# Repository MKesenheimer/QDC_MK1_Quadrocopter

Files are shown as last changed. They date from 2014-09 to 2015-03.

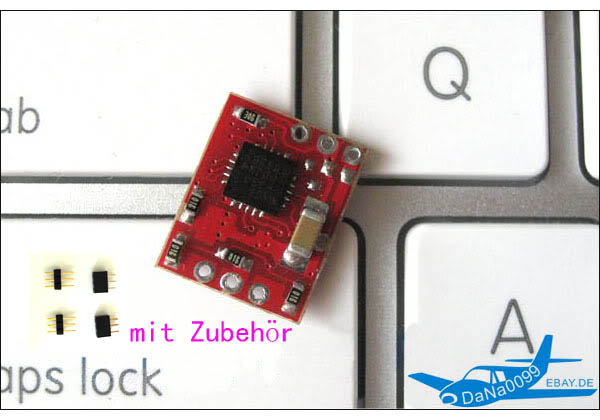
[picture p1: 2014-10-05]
hardware/Motoren + Sonstiges/yu3A.jpg

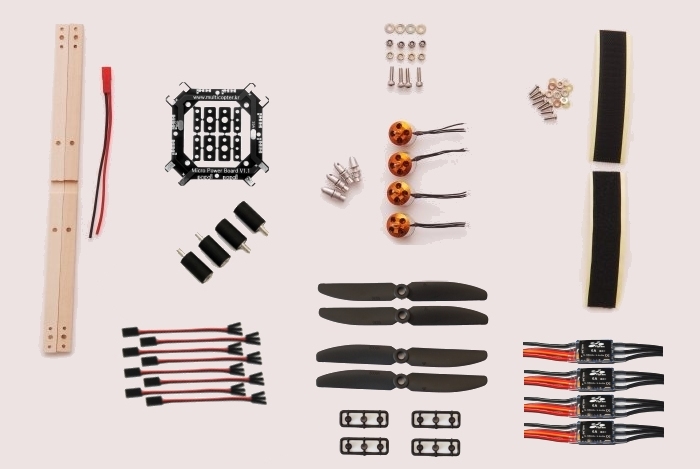
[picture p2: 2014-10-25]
hardware/Ideen/Microcopter.kr/microfullset_1.jpg

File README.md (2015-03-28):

QDC MK1 Quadrocopter
====================

Software für einen Miniatur Quadrocopter (Nanocopter) auf Grundlage der MultiWii-Software. Es wird kein Arduino, sondern ein eigenständiger Flightcontroller (AtXmega32A4) verwendet. Die Software, mit der der Quadrocopter kalibriert werden kann, läuft momentan nur unter Mac OS X.

Um die Software zu kompilieren, müssen die Mac OSX Entwicklertools (XCode) oder GNU g++ installiert sein. Außerdem wird avr-gcc und ein Hardware Programmer (z.B. JTAGICE 3) benötigt.

Kompilieren und Hochladen über PDI der Firmware auf den Quadrocopter:
---------------------------------------------------------------------
- cd firmware
- ./make_Wall oder ./make
- make flash

Erzeugen der GUI QuadroCalibration:
-----------------------------------
- QuadroCalibration.xcodeproj mit XCode öffnen
- kompilieren

Sonstiges:
----------
- der Quadrocopter muss über die serielle Schnittstelle USARTD1 mit dem Computer verbunden werden. Dazu bietet sich ein Arduino an, der standardmäßig ein USB-zu-Seriell-Konverter besitzt. Wichtig: Pegel von 3.3V nicht überschreiten!
- an der seriellen Schnittstelle USARTD0 muss der RC-Empfänger angeschlossen werden (nicht im Schaltplan verzeichnet). In dieser Software Version wird ein DSM2 fähiger Deltang rx31b-K1 verwendet.

Der Quadrocopter lässt sich über eine bestimmte Hebelstellung der Fernsteuerung scharfstellen (Motoren an/aus) und neu initialisieren (Selbstkalibrierung von GYRO und ACCELEROMETER). Siehe dazu main.c 

Bekannte Fehler
---------------
- kein Failsafe implementiert
- keine Spannungsüberwachung
- PID-Werte noch nicht optimal

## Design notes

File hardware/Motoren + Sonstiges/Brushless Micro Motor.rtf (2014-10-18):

Brushless Micro Motor:

http://www.hobbyking.com/hobbyking/store/__9666__hobbyking_ap_02_7000kv_brushless_micro_motor_2_3g_.html

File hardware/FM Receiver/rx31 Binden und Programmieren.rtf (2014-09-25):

Binden und Programmieren von rx31 (RX, Receiver) und DX6i (TX, Transmitter)

Binden
Um RX und TX zu Binden, muss die LED vom RX schnell blinken. Dazu schält man den RX ein und wartet mehrere Minuten. Das anfängliche langsame Blinken der LED geht nun in ein schnelles Blinken über und der RX ist bereit mit einem TX verbunden zu werden. Jetzt kann der TX mit gedrückter Trainer-Taste eingeschaltet werden, was das Binden von RX und TX einleitet.

Programmieren
Es gibt für den Receiver rx31 mehrere Möglichkeiten die empfangenen Rc-Werte auszugeben. Um zwischen den Modi zu wechseln, muss der RX umprogrammiert werden. Das Programmieren kann nach dem Binden von RX und TX wie folgt eingeleitet werden:
- RX ausschalten (von Spannungsquelle trennen)
- TX einschalten
- rechten und linken Steuerknüppel in die Mitte drücken (d.h. YAW nach rechts und ROLL nach links)
- RX einschalten, während die Steuerknüppel in die Mitte gedrückt werden, blinkt die LED des RX sehr schnell, das Programmieren ist bereit.

Es gibt zwei Programm Level
Level 1: Low Voltage Cutoff (brushed ESC only)
1x pro Sekunde Blinken: Disabled
2x pro Sekunde Blinken: Enabled (Default)

Level 2: Servo/Sum-PPM outputs
1x pro Sekunde Blinken: Sum-PPM on Pin3
2x pro Sekunde Blinken: Serial Data on Pin3
3x pro Sekunde Blinken: Servo outputs on all pads (Default)

Der RX zeigt nun seine derzeitige Konfiguration des ersten Programm Levels an. Blinkt er nach dem Einleiten der Programmieren ein mal pro Sekunde, heißt das, dass die Option Low Voltage Cutoff ausgeschaltet ist. Blinkt er zwei mal pro Sekunde ist die Option Low Voltage Cutoff eingeschaltet. Die derzeitige Option kann entweder mit dem rechten Steuerknüppel nach oben (NICK nach oben) akzeptiert oder mit dem rechten Steuerknüppel nach unten (NICK nach unten) verweigert werden. Wird die Option akzeptiert, geht der RX zum zweiten Level über und zeigt dort seine Konfiguration mit der entsprechenden Anzahl von Blinken pro Sekunde an. Wird die derzeitige Option allerdings verweigert, wechselt der RX zur nächsten Option, die entweder akzeptiert (weiter zum nächsten Level) oder verweigert werden kann (weiter zur nächsten Option des derzeitigen Levels).

Beispiel:
Der RX befindet sich im Werkszustand, d.h. er blinkt im ersten Level zwei mal pro Sekunde und im zweiten Level drei mal pro Sekunde.
Nun soll die folgende Konfiguration eingestellt werden:
- Low Voltage Cutoff disabled
- Serial on Pin3
Nach dem Starten des Programmiervorgangs blinkt der RX zwei mal pro Sekunden (Low Voltage Cutoff enabled). Diese Option verweigert man mit dem rechten Knüppel nach unten, weshalb der RX nun zur nächsten Option wechselt, was daran zu erkennen ist, dass der RX nur noch ein mal pro Sekunde blinkt (Low Voltage Cutoff disabled). Akzeptiert man mit dem rechten Steuerknüppel nach oben, wechselt der RX zum zweiten Programm Level und blinkt drei mal pro Sekunde. Nachdem der rechte Steuerknüppel zwei mal nach unten gedrückt wurde, ist die Option 2 ausgewählt (Serial on Pin3) und der RX blinkt zwei mal pro Sekunde. Akzeptiert man mit dem Steuerknüppel nach oben, wird die LED statisch und das Programmieren ist beendet.

Kurzversion Serial on Pin3:
(rechter Steuerknüppel nach oben H, rechter Steuerknüppel nach unten L)
Level 1:
2x Blinken: L
1x Blinken: H (Low Voltage Cutoff disabled)
-> Level 2:
3x Blinken: L
1x Blinken: L
2x Blinken: H (Serial on Pin3)
-> LED statisch

Kurzversion SUM-PPM on Pin3:
Level 1:
2x Blinken: L
1x Blinken: H (Low Voltage Cutoff disabled)
-> Level 2:
3x Blinken: L
1x Blinken: H (SUM-PPM on Pin3)
-> LED statisch

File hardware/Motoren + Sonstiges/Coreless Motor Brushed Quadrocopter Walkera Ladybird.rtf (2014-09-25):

Coreless Brushed Motor

3.7V Operating Voltage
7mm chasis Diameter
<20mm chasis length
1mm shaft diameter
0.5mNm Torque

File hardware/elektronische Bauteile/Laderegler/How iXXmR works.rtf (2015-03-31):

The way it works is when the USB power (or adapter) is not present, the VUSB_IN line gets pulled to 0V by R4. This brings the gate of the PMOS (G on the symbol) to ground and turns it on (i.e. opens the Source-Drain, marked S and D) allowing the battery to power the circuit. The Schottky (marked A and K) stops the battery raising the VUSB_IN line and turning the PMOS off again.
when the adapter is plugged in, the gate is pulled to +5V and the PMOS turns off, leaving only the adapter voltage powering the circuit and letting the battery charge.

More Current:
IRF7321D2

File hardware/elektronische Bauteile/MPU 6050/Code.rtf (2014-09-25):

Example Code

https://github.com/jrowberg/i2cdevlib

https://github.com/big5824/Quadrocopter
http://www.botched.co.uk/page/2/

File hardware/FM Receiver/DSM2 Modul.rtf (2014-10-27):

DSM2 Modul direkt auf Platine

deltang Dx31c
cyrf69103
http://deltang.co.uk/rx31b.htm

Forum Eintrag:
http://fpv-community.de/showthread.php?21520-DSM2-Nano-Empf%E4nger-auf-Nano-BL-Copter

Cyrf6936 Modul und Erklärung
https://sites.google.com/site/mrdunk/interfacing-cypress-cyrf6936-to-avr-microcontrollers

Software:
https://bitbucket.org/MatCat/letsfpv-deviation
https://bitbucket.org/MatCat/letsfpv-deviation/src

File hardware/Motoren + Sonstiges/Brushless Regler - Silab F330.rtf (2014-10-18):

Brushless Regler - eigene Platine

Als Regler habe ich eigentlich auch die kleinen 3A Regler vom Chinesen, aber eben auf meiner eigenen Platine. Das ist nichts weiter als ein Silab F330 Prozessor, ein paar wenige Widerstände und Kondensatoren und die 6 Mosfets. Als Software kann man dann die Blheli Software flashen, die kennst Du vielleicht.
Das ist der kleinste Brushlessregler den ich finden konnte, den Schaltplan gibt es glaube ich im Netz (sonst kann ich ihn dir aber auch schicken). Habe mal noch einen winzigen Chip für Laptoplüfter getestet, der war gerade mal 3x3mm groß, aber leider kam er mit den üblichen Brushlessmotoren nicht klar.

Siehe auch
http://plischka.at/Regler.html

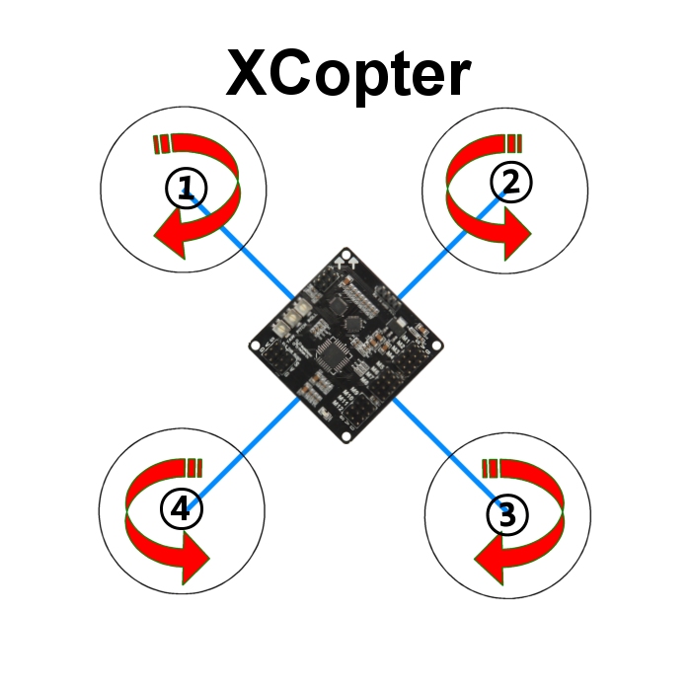
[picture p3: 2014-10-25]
hardware/Ideen/Microcopter.kr/black_x.jpg

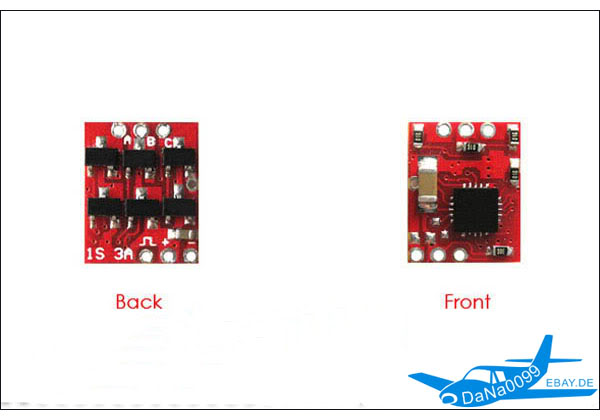
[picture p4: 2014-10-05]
hardware/Motoren + Sonstiges/ezbl-3a-1.jpg

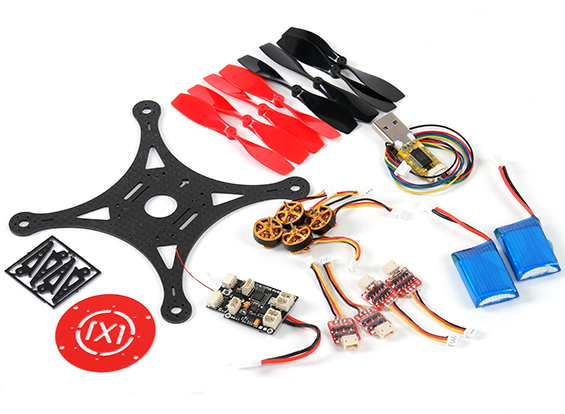
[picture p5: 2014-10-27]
hardware/Ideen/Super X.jpg

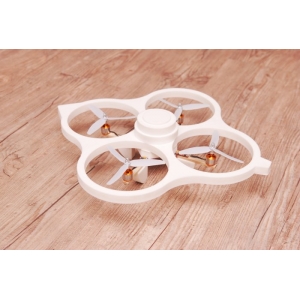
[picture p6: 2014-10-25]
hardware/Ideen/Microcopter.kr/g201207311445_152_detail.jpg

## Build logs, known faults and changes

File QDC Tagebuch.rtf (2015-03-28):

Arbeit am Quadrocopter
Oder falls das zu blöd wird: https://www.kickstarter.com/projects/1387330585/hex-a-copter-that-anyone-can-fly

15. - 16. Februar 2013:
Arbeit an xNQ_QDC_gemeinsam: Ich arbeitete weiterhin am Problem, dass die Kommunikation nicht zustande kam, wenn die UARTD0-GUI und die UARTD1-RECEIVER Schnittstelle eine zu hohe Priorität hatten. Das Problem wurde letztendlich dadurch gelöst, dass die BAUDRATE zur GUI Kommunikation mit 115200 zu groß war. Ein Reduzieren auf 19200 löste das Problem. Dadurch musste aber die MultiWii-GUI neu kompiliert werden (mit dem Programm „Processing“), da man in der GUI blöderweise die BAUDRATEs nicht ändern konnte. Außerdem musste in die Main wieder die 20ms-Abfrage eingebaut werden, damit der Mikrokontroller nicht mit der Aufgabe die RC-Daten einzulesen überlastet wurde. Die Konfiguration der seriellen Schnittstellen sieht nun so aus:

USARTD0-GUI:
- BAUD 19200
- Priorität niedrig

USARTD1-RECEIVER:
- BAUD 38400
- Priorität niedrig

Der Timer E0, der einen 10ms Interrupt aufruft, hat eine mittlere Priorität.
Da zuerst überhaupt keine RC-Daten vom RECEIVER empfangen werden konnten (mit QDC_Main_Tests_DSL getestet), musste die Initialisierung des UARTs geändert werden.
Die Variable ms10 war ursprünglich eine uint16_t Variable, was allerdings zu Problemen führte, weil sie überlief. Sie wurde auf uint32_t geändert.

noch Problem: Die RC-Daten werden nicht korrekt empfangen. Wird der Sender angeschaltet, verändern sich zwar kurz die Werte in der MultiWii-GUI, aber sie lassen sich nicht mit den Steuerknüppeln ändern. Ich vermute, dass noch irgendetwas mit den Interrupts nicht stimmt oder dass in receive.c noch ein Fehler ist.
Dazu hab ich mir meine alten Codes (z.B. BIG5824) angeschaut, wo die RC-Daten korrekt übertragen werden.

Arbeit an QDC_Main_Project_BIG5824: Alle _delay_ms() wurden durch _delay_loop_2() ausgetauscht. Ich vermutete, dass die alten Warteschleifen Probleme bereiteten. Dem war aber nicht so. Der Timer-Aufruf von E0 wurde so geändert, dass er nur noch alle 10ms einen Interrupt auslöst. Damit verhindere ich hohe Interruptauslastung.

Arbeit an QuadroCalibration: Aufgrund der Hardwareänderung, dass die Kommunikation jetzt nicht mehr über den Arduino, sondern direkt über die serielle Schnittstelle läuft, wurde der Default-Wert beim PopUp der BAUDRATEs auf 19200 geändert.

23. Februar
Arbeit an xNQ_QDC_gemeinsam: Das Empfangen der RcDaten funktioniert einigermaßen. Ich bin mir noch nicht sicher, ob die Kanalzuordnung stimmt. Zuerst änderten sich die Werte in der GUI nicht (Fehler der vergangenen Woche), weil das Intervall der rcData[] Werte nicht passte und ein Constrain() sie auf 100 einschränkte. Außerdem kalibriert sich das ACC manchmal wieder neu, danach hatte ACC_Z einen zu niedrigen Wert. Letzteres wurde dadurch korrigiert, dass das Vorzeichen beim Lesen der ACC_Z Werte aus dem ADC geändert wurde. Nun können die ACC_Z Werte allerdings nach einem Kalibrationsvorgang sehr groß sein, was allerdings egal ist, denn sie werden jetzt wieder richtig korrigiert. Das zufällige Einsetzen der Kalibration bleibt allerdings weiterhin ungeklärt. Vielleicht hat es tatsächlich mit Störungen des RC_Empfängers zu tun oder die Kalibrationsvorgänge werden durch die GUI getriggert. Diese Idee ist vielleicht gar nicht so abwegig, denn der QDC kalibriert sich nicht neu, wenn er nicht an die GUI angeschlossen ist.
Bleibt also noch die Frage zu klären, warum ein Kalibrationsvorgang ausgelöst wird, wenn rcData[ROLL] oder PITCH sehr groß ist -> sind das die f.ARMED Abfragen?

8. Juli (Updates vom 22. September)
Hinweise: Es ist jedes mal ein Problem alles zum Laufen zu bekommen, wenn man schon lange nichts mehr am Quadrocopter gearbeitet hat. Deshalb hier die Kurzzusammenfassung, was getan werden muss um den Quadrocopter mit dem Host (Computer) zu verbinden.
- Um den Quadrocopter mit dem Programm MultiWiiConf (zu finden in Firmware QDC MK I/Host Software) zu verbinden muss der Quadrocopter mit der Firmware xNQ_QDC_gemeinsam geflasht werden.
- Um den Quadrocopter mit dem Programm QuadroCalibration zu verbinden muss der Quadrocopter mit der Firmware QDC_Main_Project oder QDC_Main_Project_BIG5824 geflasht werden.
- Auf der Arduino-Seite reicht es die Datenleitungen (gelb und weiß) in die schwarze Headerleiste einzustecken. Es muss keine spezielle Software auf den Arduino installiert werden. Zur Sicherheit kann das Programm SoftwareSerial (zu finden in Firmware QDC MK I/Host Software/Arduino Programm/SoftwareSerial) geladen werden.
- Außerdem darauf achten, dass die Spannung des Arduinos auf 3.3V eingestellt ist!
- Falls die Verbindung nicht zustande kommt, den Quadrocopter neu starten oder den Akku des Quadrocopters aufladen.

Arbeit an DSM2 Übertragung: Weiterhin Problem, dass die RC-Roll-Werte nicht ankommen. Mit dem Arduino-Oszilloskop wurde allerdings gemessen, dass sich die Impulsbreite ändert, wenn der Roll-Knüppel bewegt wird. Also kann es nicht an der Fernsteuerung liegen. Liegt es am rx31 oder an der Software?

17. Juli
Arbeit an der Hardware: Endlich! Das Problem mit den Roll-Werten ist gelöst! Nachdem ich einen neuen Empfänger rx31c-K1 gekauft habe, funktioniert alles auf Anhieb. Den alten Empfänger (rx31b-F) konnte ich Umtauschen und erhielt dafür einen weiteren rx31c-K1, den ich nun in Domis Quadrocopter einbaue.
Der 35MHz Sender (Robbe Futaba FX-14) wird nun auf Ebay verkauft und dafür ein „Pommessender“ MLP4DSM oder LP5DSM von E-FLITE für Domi gekauft.

7. September
Arbeit an den TODOs: QDX_Main_Project lässt sich nun wieder kompilieren. (Klammerfehler in config.c)

19. September
Arbeit an der Hardware: Beide Quadrocopter wurden nun mit dem rx31c-K1 aufgerüstet, sodass beide Quadrocopter mit der DX6i, d.h. Spektrum-fähig sind. Hier die neue Übersicht der belegten Ports:
USARTD0: rx31c-K1 Empfänger
USARTD1: Debug-Schnittstelle zum Host
Außerdem wurde ein Splitter gebaut, der die serielle Debug-Schnittstelle von der JTAGICE3-Schnittstelle trennt. Jetzt kann gleichzeitig programmiert und auf der Debug-Schnittstelle Daten gesammelt werden, ohne dass umgesteckt werden muss!
Arbeit an QDC_Main_Project: Hier wurde mit der Umstellung des Programmcodes auf die neue Verkabelung begonnen (RC=USARTD0, DEBUG=USARTD1).
Allerdings funktioniert das Empfangen der RC-Daten noch nicht (TODO!).

22. September
Arbeit an QDC_Main_Project_BIG5824: Die Software wurde auf die Verkabelung mit dem rx31c-K1 Empfängers umgestellt. Die Warnungen wurden entfernt.
Arbeit an QDC_Main_Project: Die Software wurde auf die Verkabelung mit dem rx31c-K1 Empfängers umgestellt. Die Warnungen wurden entfernt.

23.-24. September
Arbeit an QDC_Main_Project_BIG5824:
- Blinken der LEDs wurde eingebaut
- Ausgabe auf die Motoren wurde programmiert
- Verbesserungen am PID Algorithmus
- erste Versuche den Quadrocopter mit dieser Software fliegen zu lassen -> PID muss noch besser eingestellt werden

25. September
Arbeit an QDC_Main_Project_BIG5824: Ein Kalman Filter wurde erfolgreich implementiert. Dazu war http://robottini.altervista.org/tag/complementary-filter hilfreich.
Das ganze Quadrocopter Projekt wurde ein bisschen besser strukturiert und auf Github hochgeladen. Das Projekt heißt jetzt "QDC_MK1_Quadrocopter" und ist ein Ableger von QDC_Main_Project_BIG5824.
QDC_Main_Project_BIG5824 heißt jetzt QDC_MK1_Quadrocopter.
Außerdem wurde serial.c überarbeitet. Der Code ist nun eleganter und kürzer.

26.-29. September
Arbeit an QDC_MK1_Quadrocopter: In der GUI wurde eine Debug-Option eingebaut. Jetzt können mit Check-Boxen zehn verschiedene Debug-Werte ausgewählt und geplottet werden. Das Programm kann noch mit dem Einsatz von Arrays verbessert werden.
Außerdem werden die Motorwerte und die cycle time während der Konfiguration angezeigt, was ebenfalls die Fehlersuche bzw. das Einstellen des QDC erleichtert. In pid.c wurde der Constrain der Integralwerte herabgesetzt, so reagiert der QDC schneller auf andauernde Störungen. Der LowPassFilter wurde wieder auf 42Hz geändert und der SecondOrderComplementaryFilter wird wieder benutzt, was denke ich gute Resultate erzielt.
Flugversuche sehen vielversprechend aus.

30. September
Arbeit an den PID-Werten: Beim Einstellen und Testen der PID-Werte ging ein Motor kaputt. Vier neue Motoren bei Ebay bestellt.

06. Oktober bis -
Arbeit an Schaltplan für Version 2:
Für die zweite Version des Quadrocopters sind einige Verbesserungen vorgesehen:
- prinzipiell sind für die Version 2 zwei Platinen vorgesehen. Auf der ersten befindet sich die Flugsteuerung (IMU, µC, PWM-Ausgang, Receiver-Eingang) und auf der zweiten die Motortreiber, Spannungsversorgung, Laderegler usw. Die zweite Platine dient gleichzeitig als Rahmen und Motorhalter. Beide Platinen könnten über UART miteinander verbunden werden (was allerdings einen zweiten µC auf der Motorplatine nötig macht).
- Die Platine für die Flugsteuerung soll wie die CC3D oder MultiWii mehrere Quadrocopter-Arten (Quadrocopter, ) ansteuern können.
- Brushless Motoren (z.B. HobbyKing 7000kv Brushless Micro Motor) sollen mit Onboard-Reglern (SiLab F330 und Blheli Software) nativ angesteuert werden können (keine zusätzlichen Platinen)
- Brushed Motoren sollen weiterhin unterstützt werden
- Laderegler für das Laden des LiPos über USB
- Power über USB (Programmieren, Parameter, Debug)
- Flugsteuerung auf extra Platine, die mit Schaumstoff vom Rest der Platine entkoppelt wird (bessere Störungsentkopplung)
- ggf. werden Ausleger und Motorbefestigungen geändert
- besseres Routing

TODO:
- TODOs in IMU.c
- Ausprobieren: Kalman Filter, DLPF = 12.5Hz (http://www.instructables.com/id/PCB-Quadrotor-Brushless/?ALLSTEPS, Video ganz unten)
- Platine für Version 2 vorbereiten. Der Gyro und Acc soll außerdem durch einen Kompass erweitert werden: MPU9150
- Rext gegen 120Ohm austauschen
- Für Brushless Betrieb: EAZY 3A (ESC)
- Lipo Laderegler: http://www.roboternetz.de/community/threads/61909-nanoCopter-Projekt

In ferner Zukunft TODO:
- Die serielle Kommunikation in QuadroCalibration.app ändern: Erst auf Nachfrage der GUI soll der QDC einen bestimmten Wert senden.

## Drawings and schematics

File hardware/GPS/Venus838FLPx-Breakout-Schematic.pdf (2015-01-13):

D

6 | 5 | 4 | 3 | 2 | 1

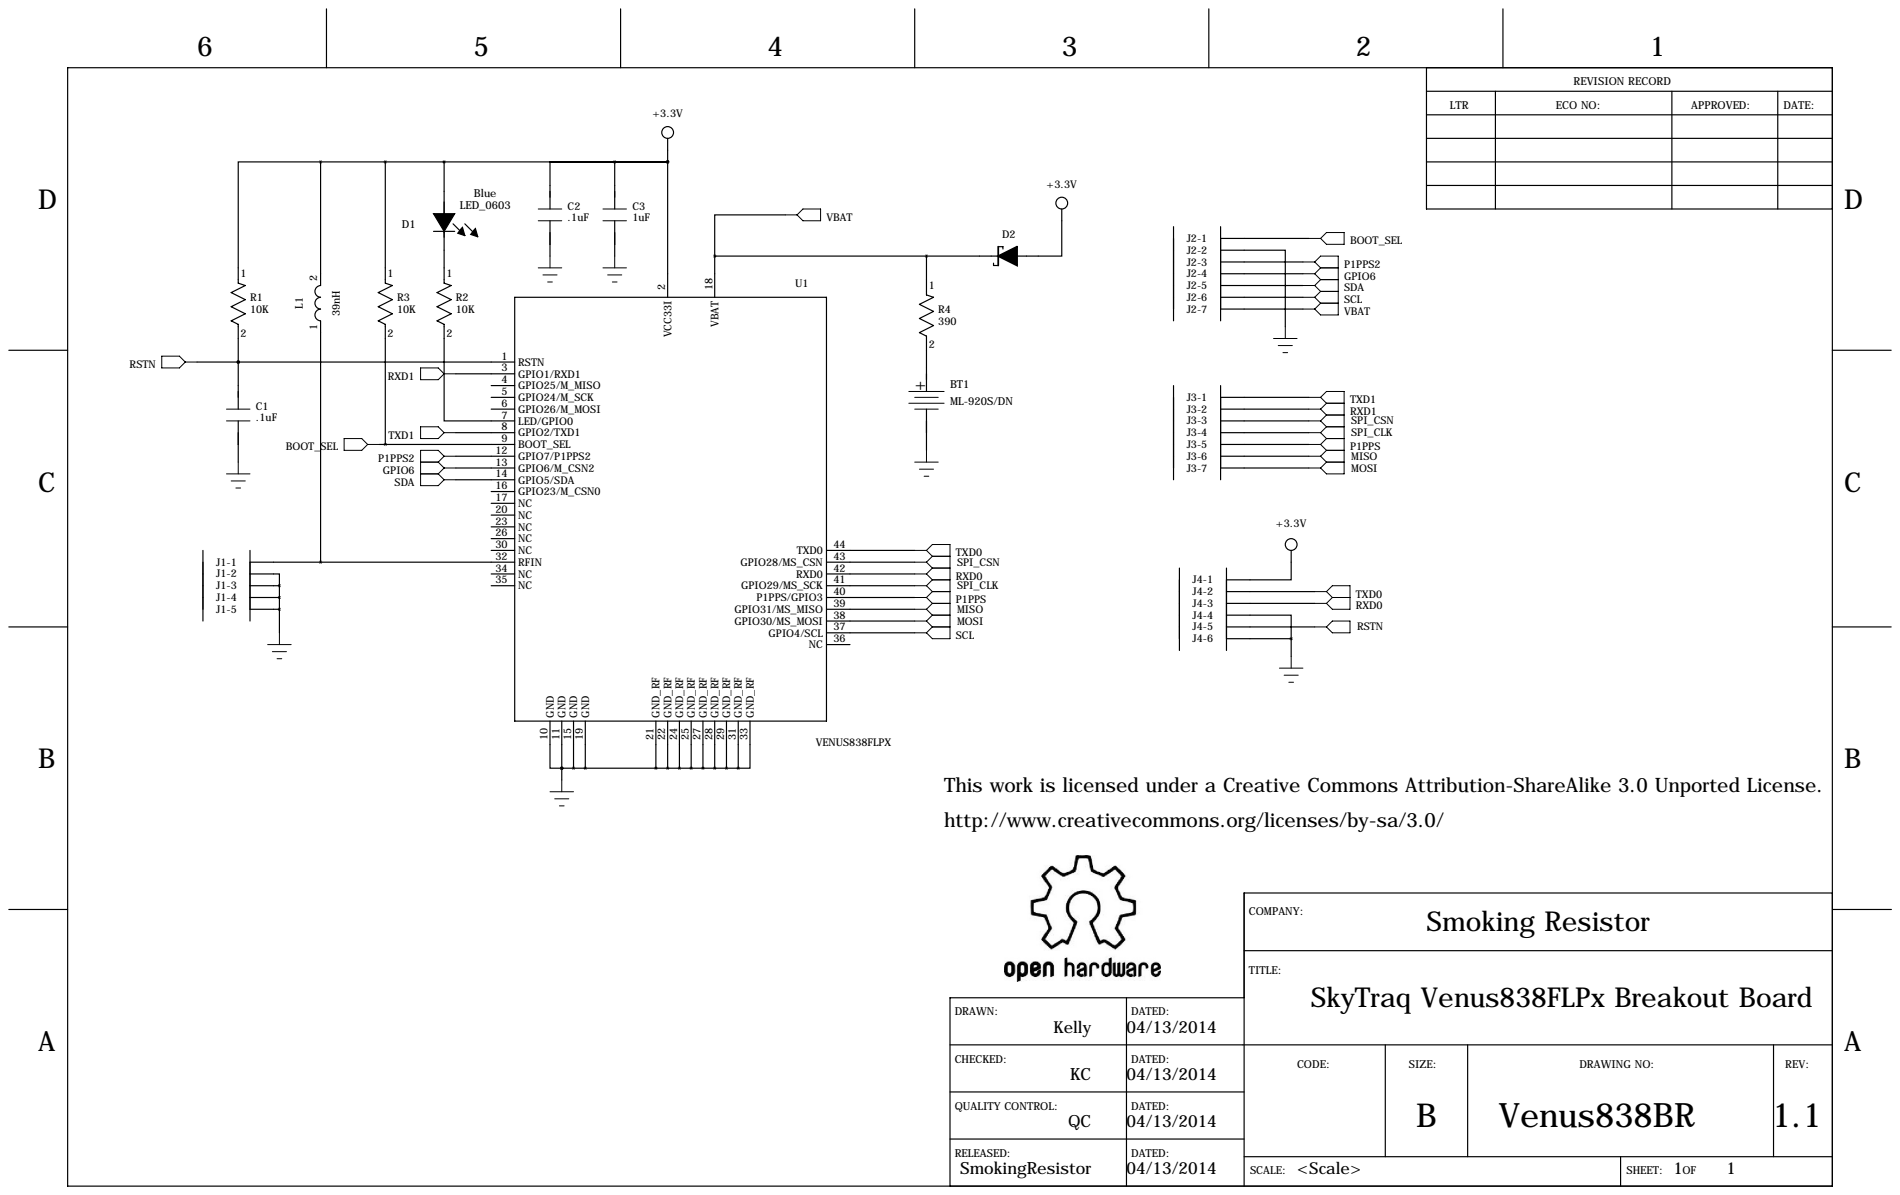
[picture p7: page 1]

+3.3V | REVISION RECORD

LTR | ECO NO: | APPROVED: | DATE:

This work is licensed under a Creative Commons Attribution-ShareAlike 3.0 Unported License.

http://www.creativecommons.org/licenses/by-sa/3.0/

DRAWN: Kelly | DATED: 04/13/2014
CHECKED: KC | DATED: 04/13/2014 | CODE: | SIZE: B | DRAWING NO: Venus838BR | REV: 1.1

QUALITY CONTROL: QC | DATED: 04/13/2014

RELEASED: SmokingResistor | DATED: 04/13/2014

<Scale> SCALE: | 1 1 SHEET: OF

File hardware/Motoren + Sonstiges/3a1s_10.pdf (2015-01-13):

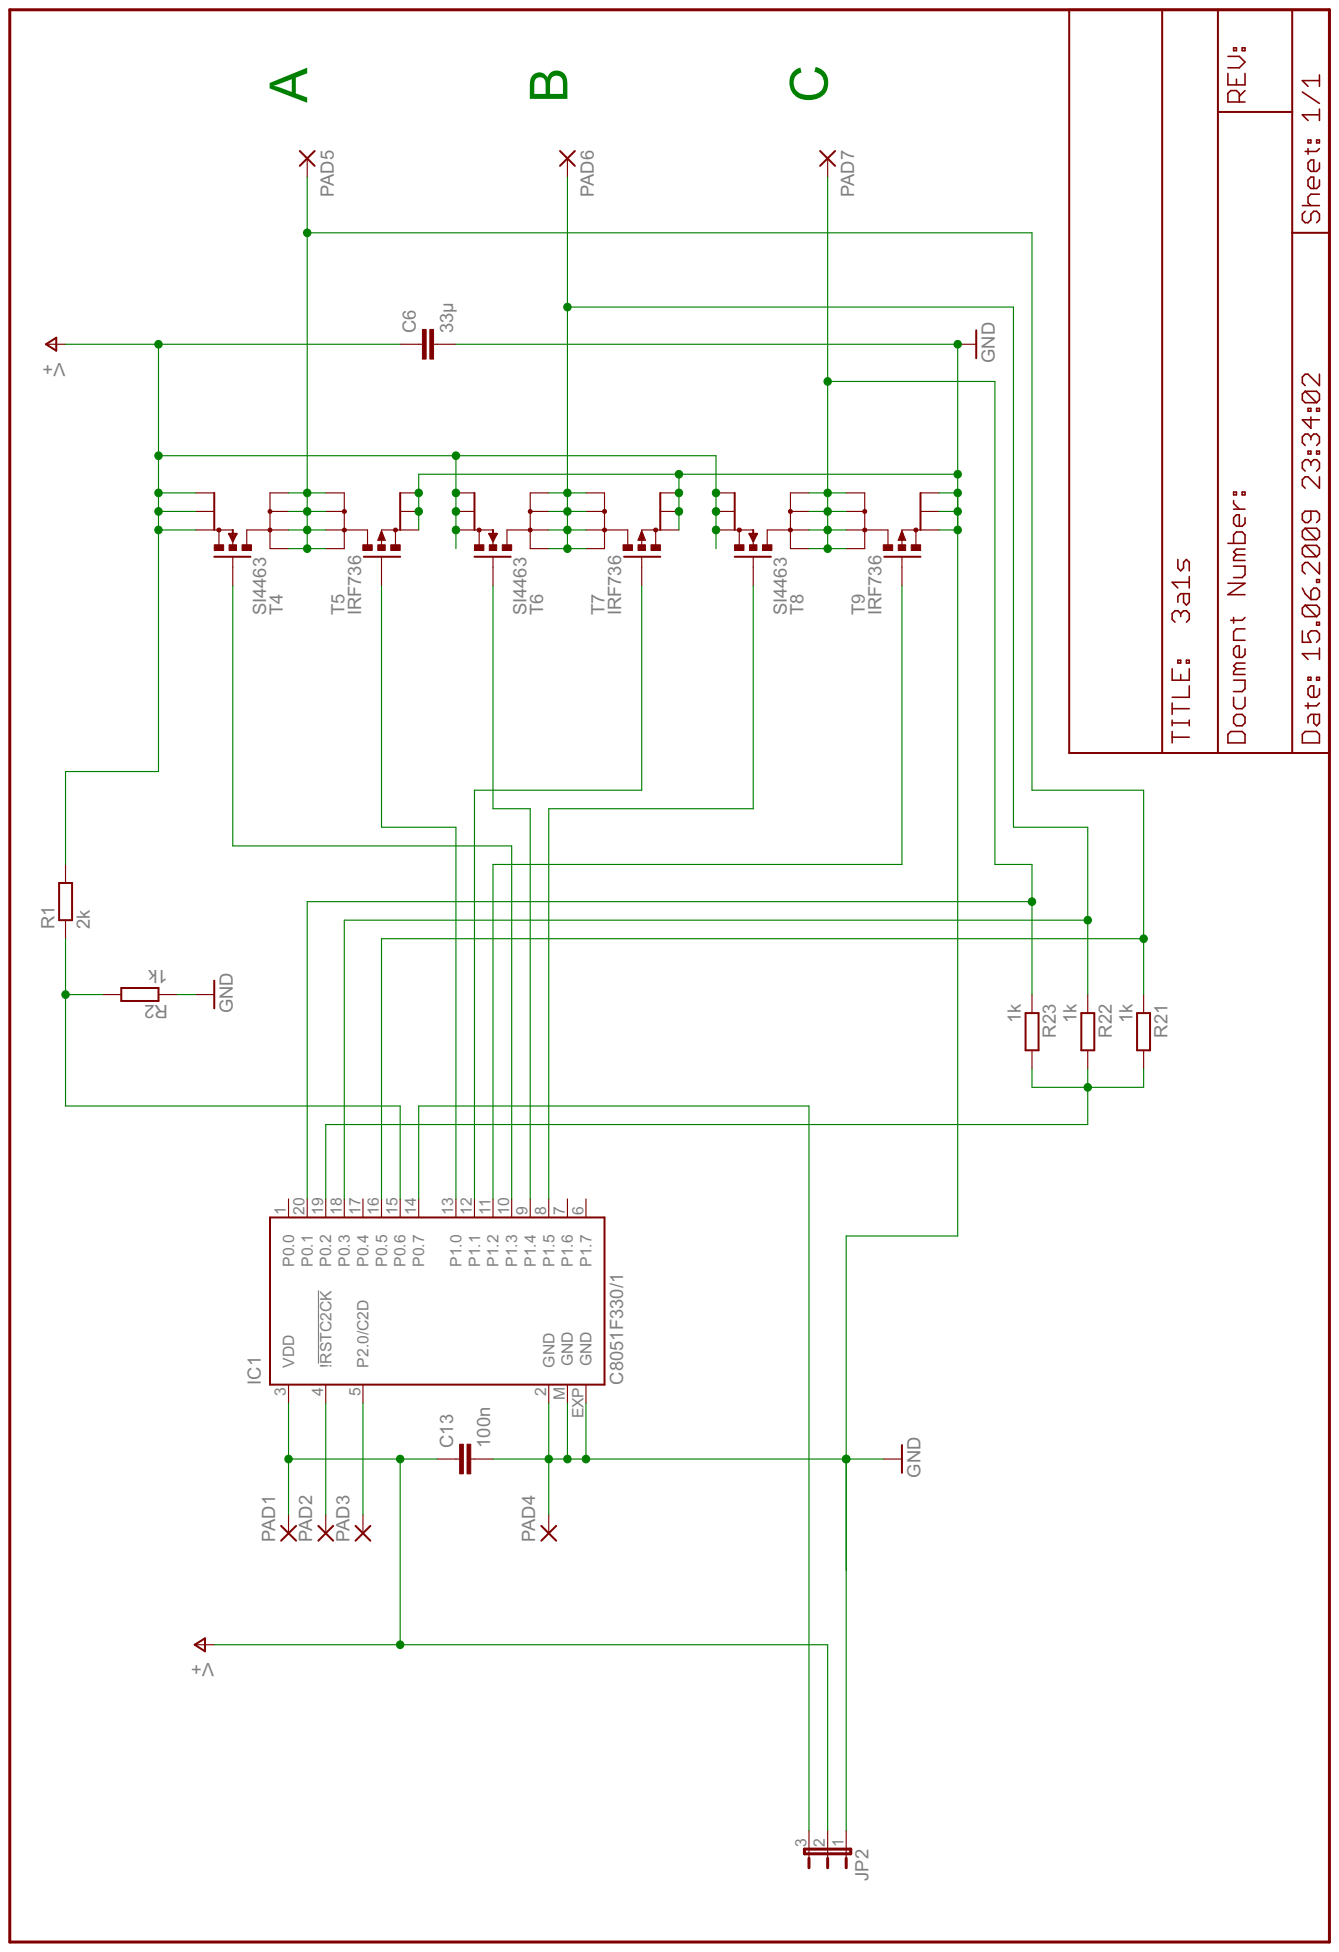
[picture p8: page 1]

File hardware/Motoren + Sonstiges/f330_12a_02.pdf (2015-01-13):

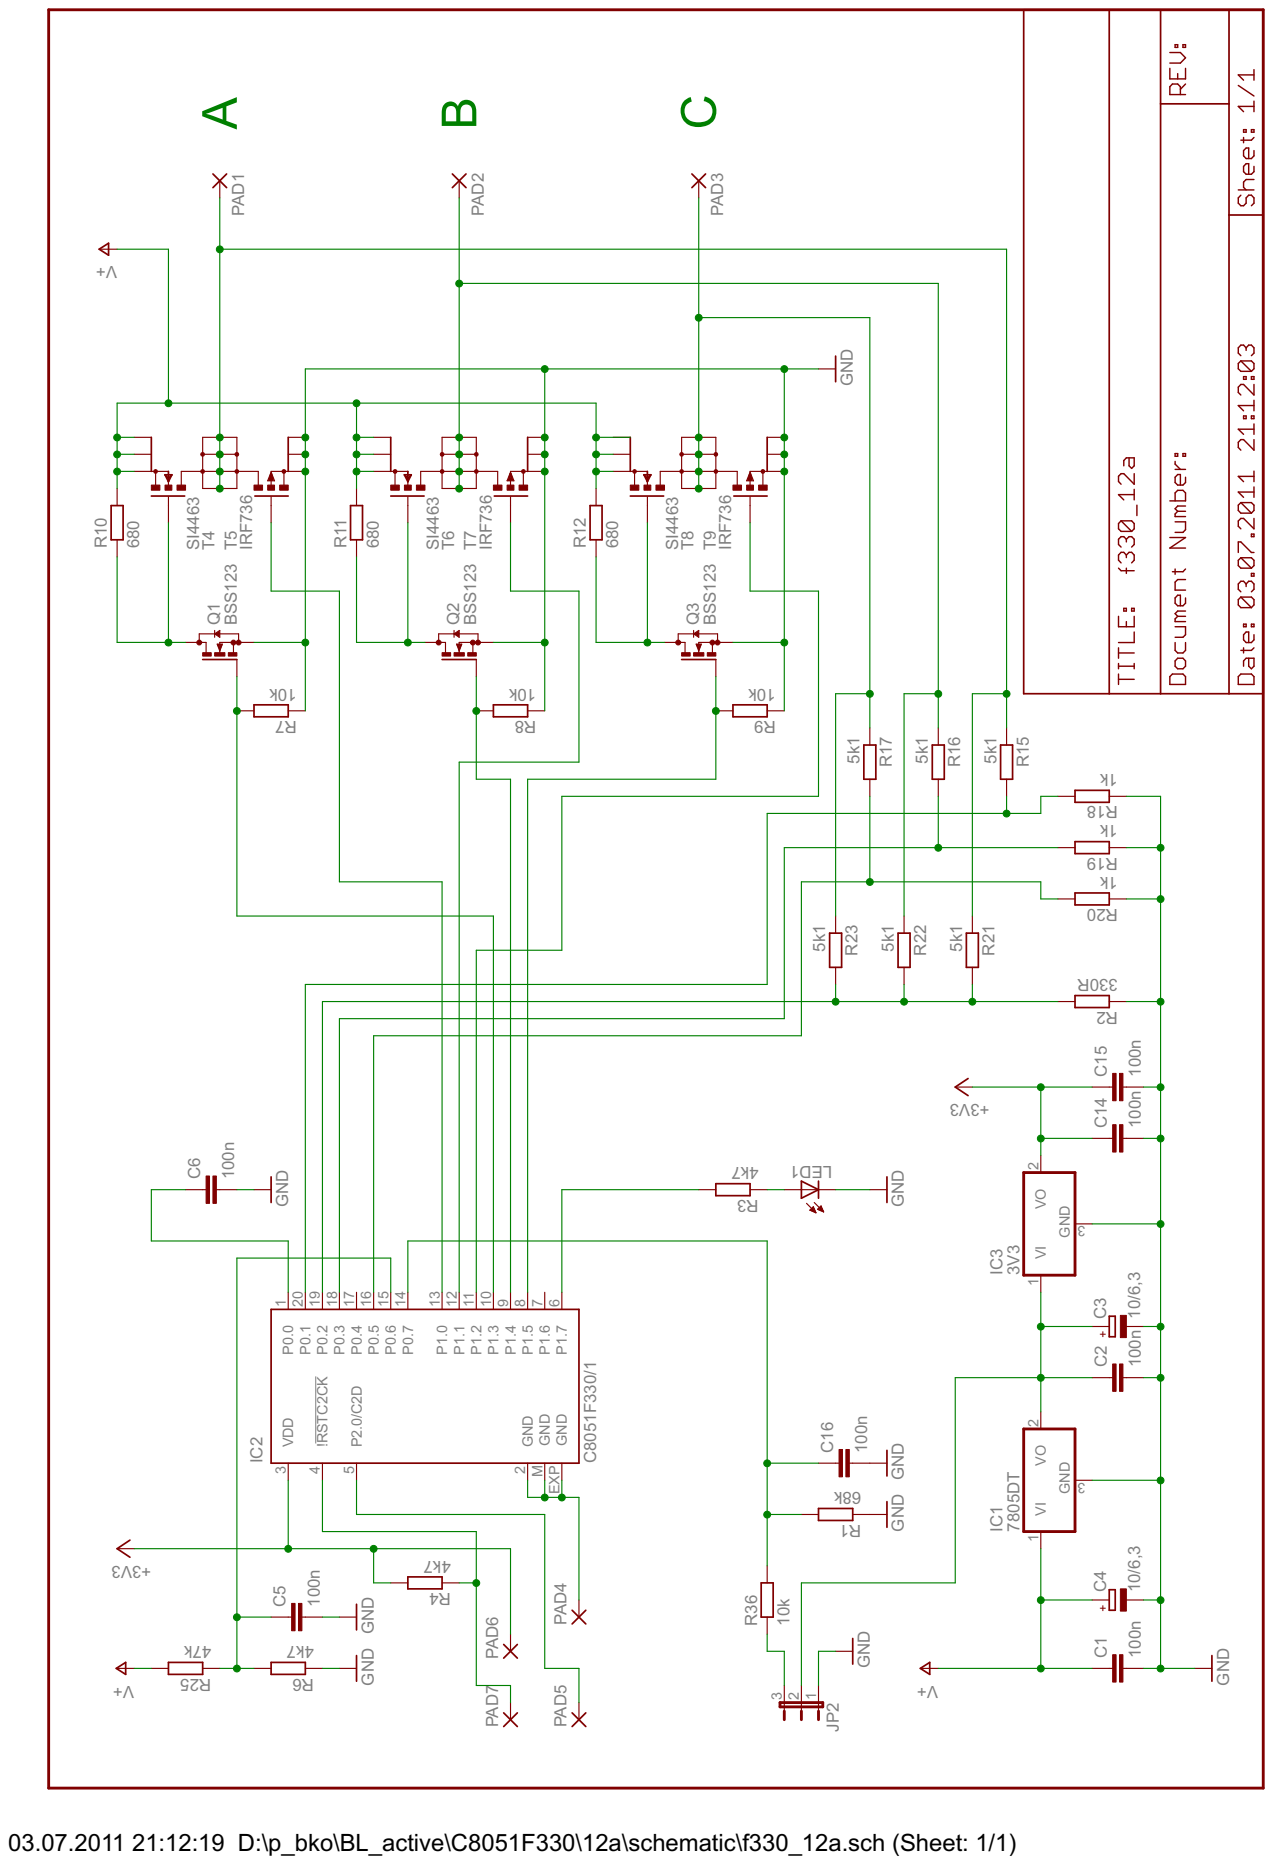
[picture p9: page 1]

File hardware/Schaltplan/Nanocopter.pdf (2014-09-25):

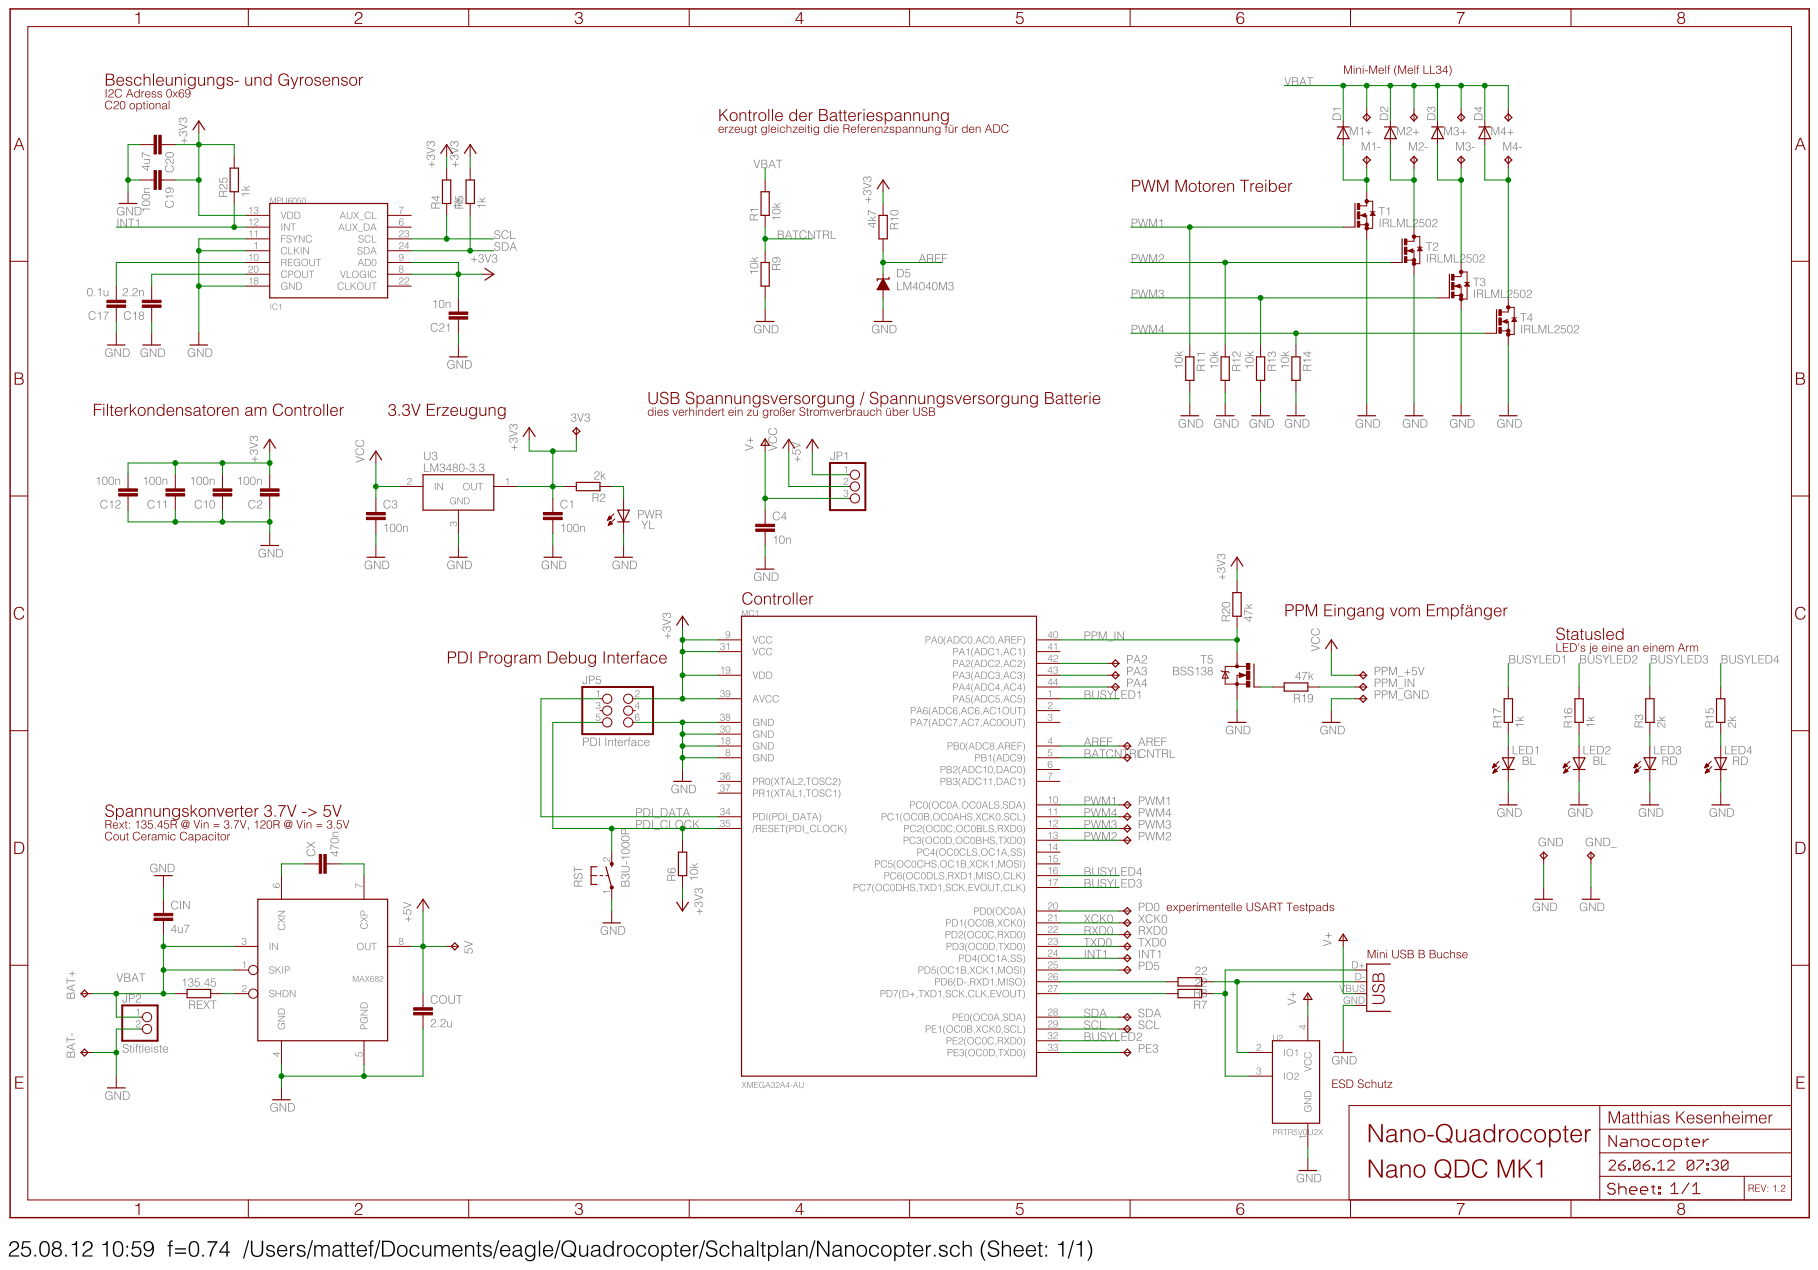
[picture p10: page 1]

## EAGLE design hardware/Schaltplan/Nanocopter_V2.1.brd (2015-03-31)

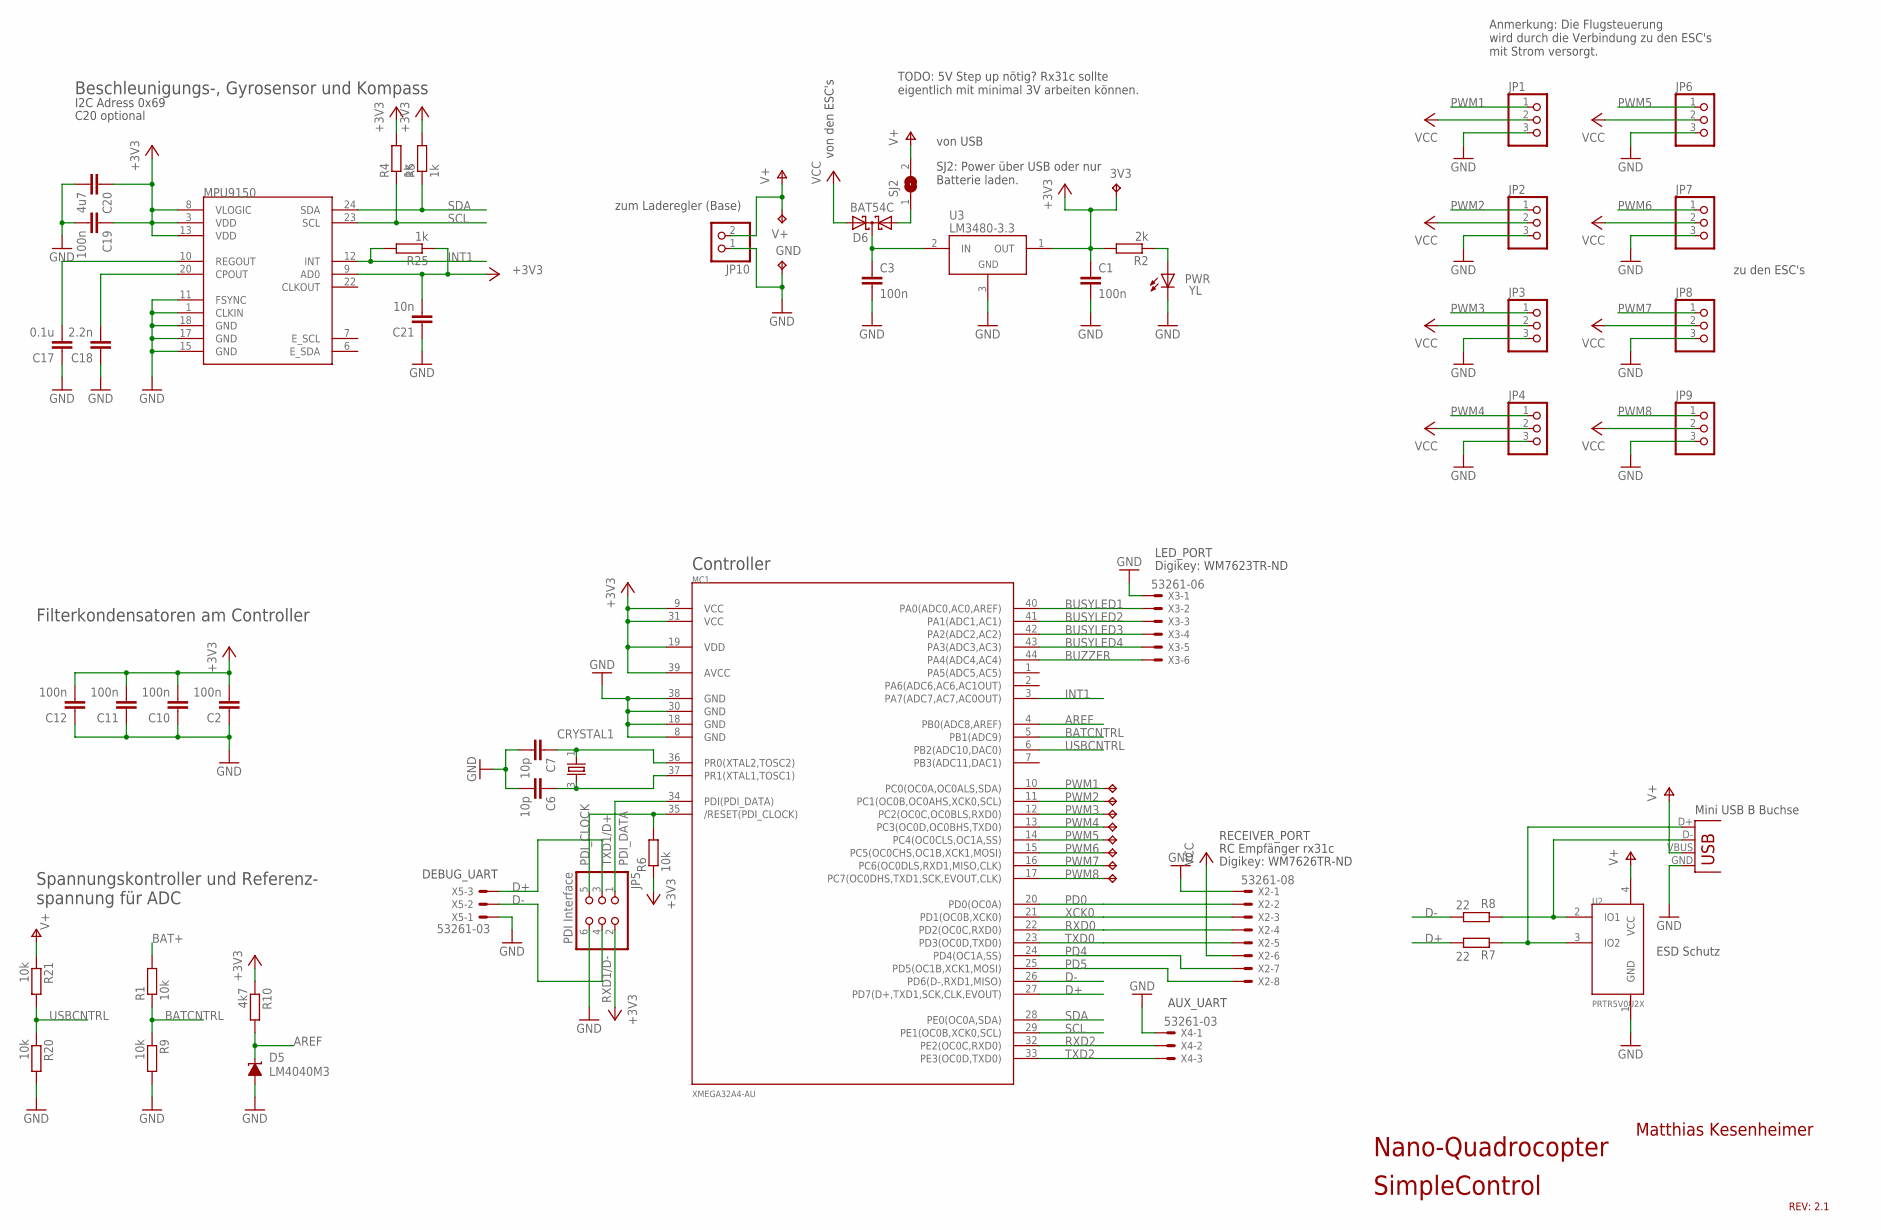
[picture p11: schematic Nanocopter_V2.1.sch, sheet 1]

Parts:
3V1, 3V2, 3V3, 3V4, 3V5, 3V6, 3V7, 3V8: TPTP12SQ; TP12SQ
C1, C2, C3, C10, C11, C12, C19: 100n; C0603
C6, C7: 10p; C0603
C17: 0.1u; C0603
C18: 2.2n; C0603
C20: 4u7; C0603
C21: 10n; C0603
CRYSTAL1: CRYSTAL4PIN; CRYSTAL-4PIN
D5: LM4040M3; SOT-23
D6: BAT54C; SOT23
GND: TPTP12SQ; TP12SQ
JP1, JP2, JP3, JP4, JP6, JP7, JP8, JP9: PINHD-1X3; 1X03
JP5: PDI Interface; 2X03
JP10: PINHD-1X2; 1X02
MC1: XMEGA32A4-AU; TQFP44
MPU9150: MPU-9150QFN-24-NP; QFN-24-NP
PWM1: TPTP12SQ; TP12SQ
PWR: YL; CHIPLED_0603
R1, R6, R9, R20, R21: 10k; R0603
R2: 2k; R0603
R4, R5, R25: 1k; R0603
R7, R8: 22; R0603
R10: 4k7; R0603
SJ2: SJ
U2: PRTR5V0U2X; SOT143B
U3: LM3480-3.3; SOT-23-3
V+: TPTP12SQ; TP12SQ
X1: USBSMD; USB-MINIB
X2: 53261-08
X3: 53261-06
X4, X5: 53261-03

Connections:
+3V3: 3V3.TP, C1.1, C2.2, C10.2, C11.2, C12.2, C19.1, C20.1, C21.2, JP5.2, MC1.9 (VCC), MC1.19 (VDD), MC1.31 (VCC), MC1.39 (AVCC), MPU9150.3 (VDD), MPU9150.8 (VLOGIC), MPU9150.9 (AD0), MPU9150.13 (VDD), R2.2, R4.2, R5.2, R6.1, R10.1, R25.1, U3.1 (OUT)
AREF: D5.1 (C), MC1.4 (PB0(ADC8,AREF)), R10.2
BAT+: R1.2
BATCNTRL: MC1.5 (PB1(ADC9)), R1.1, R9.1
BUSYLED1: MC1.40 (PA0(ADC0,AC0,AREF)), X3.2
BUSYLED2: MC1.41 (PA1(ADC1,AC1)), X3.3
BUSYLED3: MC1.42 (PA2(ADC2,AC2)), X3.4
BUSYLED4: MC1.43 (PA3(ADC3,AC3)), X3.5
BUZZER: MC1.44 (PA4(ADC4,AC4)), X3.6
D+: JP5.3, MC1.27 (PD7(D+,TXD1,SCK,CLK,EVOUT)), R7.2, X5.3
D-: JP5.4, MC1.26 (PD6(D-,RXD1,MISO)), R8.2, X5.2
GND: C1.2, C2.1, C3.2, C6.2, C7.2, C10.1, C11.1, C12.1, C17.1, C18.1, C19.2, C20.2, C21.1, D5.2 (A), GND.TP, JP1.3, JP2.3, JP3.3, JP4.3, JP5.6, JP6.3, JP7.3, JP8.3, JP9.3, JP10.1, MC1.8 (GND), MC1.18 (GND), MC1.30 (GND), MC1.38 (GND), MPU9150.1 (CLKIN), MPU9150.11 (FSYNC), MPU9150.15 (GND), MPU9150.17 (GND), MPU9150.18 (GND), PWR.C, R9.2, R20.2, U2.1 (GND), U3.3 (GND), X1.GND, X2.1, X3.1, X4.1, X5.1; also elsewhere on the board
INT1: MC1.3 (PA7(ADC7,AC7,AC0OUT)), MPU9150.12 (INT), R25.2
unnamed: C18.2, MPU9150.20 (CPOUT)
unnamed: C17.2, MPU9150.10 (REGOUT)
unnamed: C3.1, D6.3 (CC), U3.2 (IN)
unnamed: PWR.A, R2.1
unnamed: C7.1, CRYSTAL1.1, MC1.36 (PR0(XTAL2,TOSC2))
unnamed: C6.1, CRYSTAL1.3 (2), MC1.37 (PR1(XTAL1,TOSC1))
unnamed: D6.1 (A1), SJ2.1
PD0: MC1.20 (PD0(OC0A)), X2.2
PD4: MC1.24 (PD4(OC1A,SS)), X2.7
PD5: MC1.25 (PD5(OC1B,XCK1,MOSI)), X2.8
PDI_CLOCK: JP5.5, MC1.35 (/RESET(PDI_CLOCK)), R6.2
PDI_DATA: JP5.1, MC1.34 (PDI(PDI_DATA))
PWM1: JP1.1, MC1.10 (PC0(OC0A,OC0ALS,SDA)), PWM1.TP
PWM2: 3V2.TP, JP2.1, MC1.11 (PC1(OC0B,OC0AHS,XCK0,SCL))
PWM3: 3V4.TP, JP3.1, MC1.12 (PC2(OC0C,OC0BLS,RXD0))
PWM4: 3V5.TP, JP4.1, MC1.13 (PC3(OC0D,OC0BHS,TXD0))
PWM5: 3V1.TP, JP6.1, MC1.14 (PC4(OC0CLS,OC1A,SS))
PWM6: 3V6.TP, JP7.1, MC1.15 (PC5(OC0CHS,OC1B,XCK1,MOSI))
PWM7: 3V7.TP, JP8.1, MC1.16 (PC6(OC0DLS,RXD1,MISO,CLK))
PWM8: 3V8.TP, JP9.1, MC1.17 (PC7(OC0DHS,TXD1,SCK,EVOUT,CLK))
RXD0: MC1.22 (PD2(OC0C,RXD0)), X2.4
RXD2: MC1.32 (PE2(OC0C,RXD0)), X4.2
SCL: MC1.29 (PE1(OC0B,XCK0,SCL)), MPU9150.23 (SCL), R4.1
SDA: MC1.28 (PE0(OC0A,SDA)), MPU9150.24 (SDA), R5.1
TXD0: MC1.23 (PD3(OC0D,TXD0)), X2.5
TXD2: MC1.33 (PE3(OC0D,TXD0)), X4.3
USB+: R7.1, U2.3 (IO2), X1.D+
USB-: R8.1, U2.2 (IO1), X1.D-
USBCNTRL: MC1.6 (PB2(ADC10,DAC0)), R20.1, R21.2
V+: JP10.2, R21.1, SJ2.2, U2.4 (VCC), V+.TP, X1.VBUS
VCC: D6.2 (A2), JP1.2, JP2.2, JP3.2, JP4.2, JP6.2, JP7.2, JP8.2, JP9.2, X2.6; also elsewhere on the board
XCK0: MC1.21 (PD1(OC0B,XCK0)), X2.3

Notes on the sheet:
I2C Adress 0x69
Beschleunigungs-, Gyrosensor und Kompass
Matthias Kesenheimer
REV: 2.1
Nano-Quadrocopter
SimpleControl
Mini USB B Buchse
Controller
Filterkondensatoren am Controller
C20 optional
Spannungskontroller und Referenz- spannung für ADC
ESD Schutz
RC Empfänger rx31c
Digikey: WM7626TR-ND
Digikey: WM7623TR-ND
RXD1/D-
TXD1/D+
DEBUG_UART
AUX_UART
LED_PORT
RECEIVER_PORT
zum Laderegler (Base)
zu den ESC's
Anmerkung: Die Flugsteuerung wird durch die Verbindung zu den ESC's mit Strom versorgt.
von den ESC's
von USB
SJ2: Power über USB oder nur Batterie laden.
TODO: 5V Step up nötig? Rx31c sollte eigentlich mit minimal 3V arbeiten können.

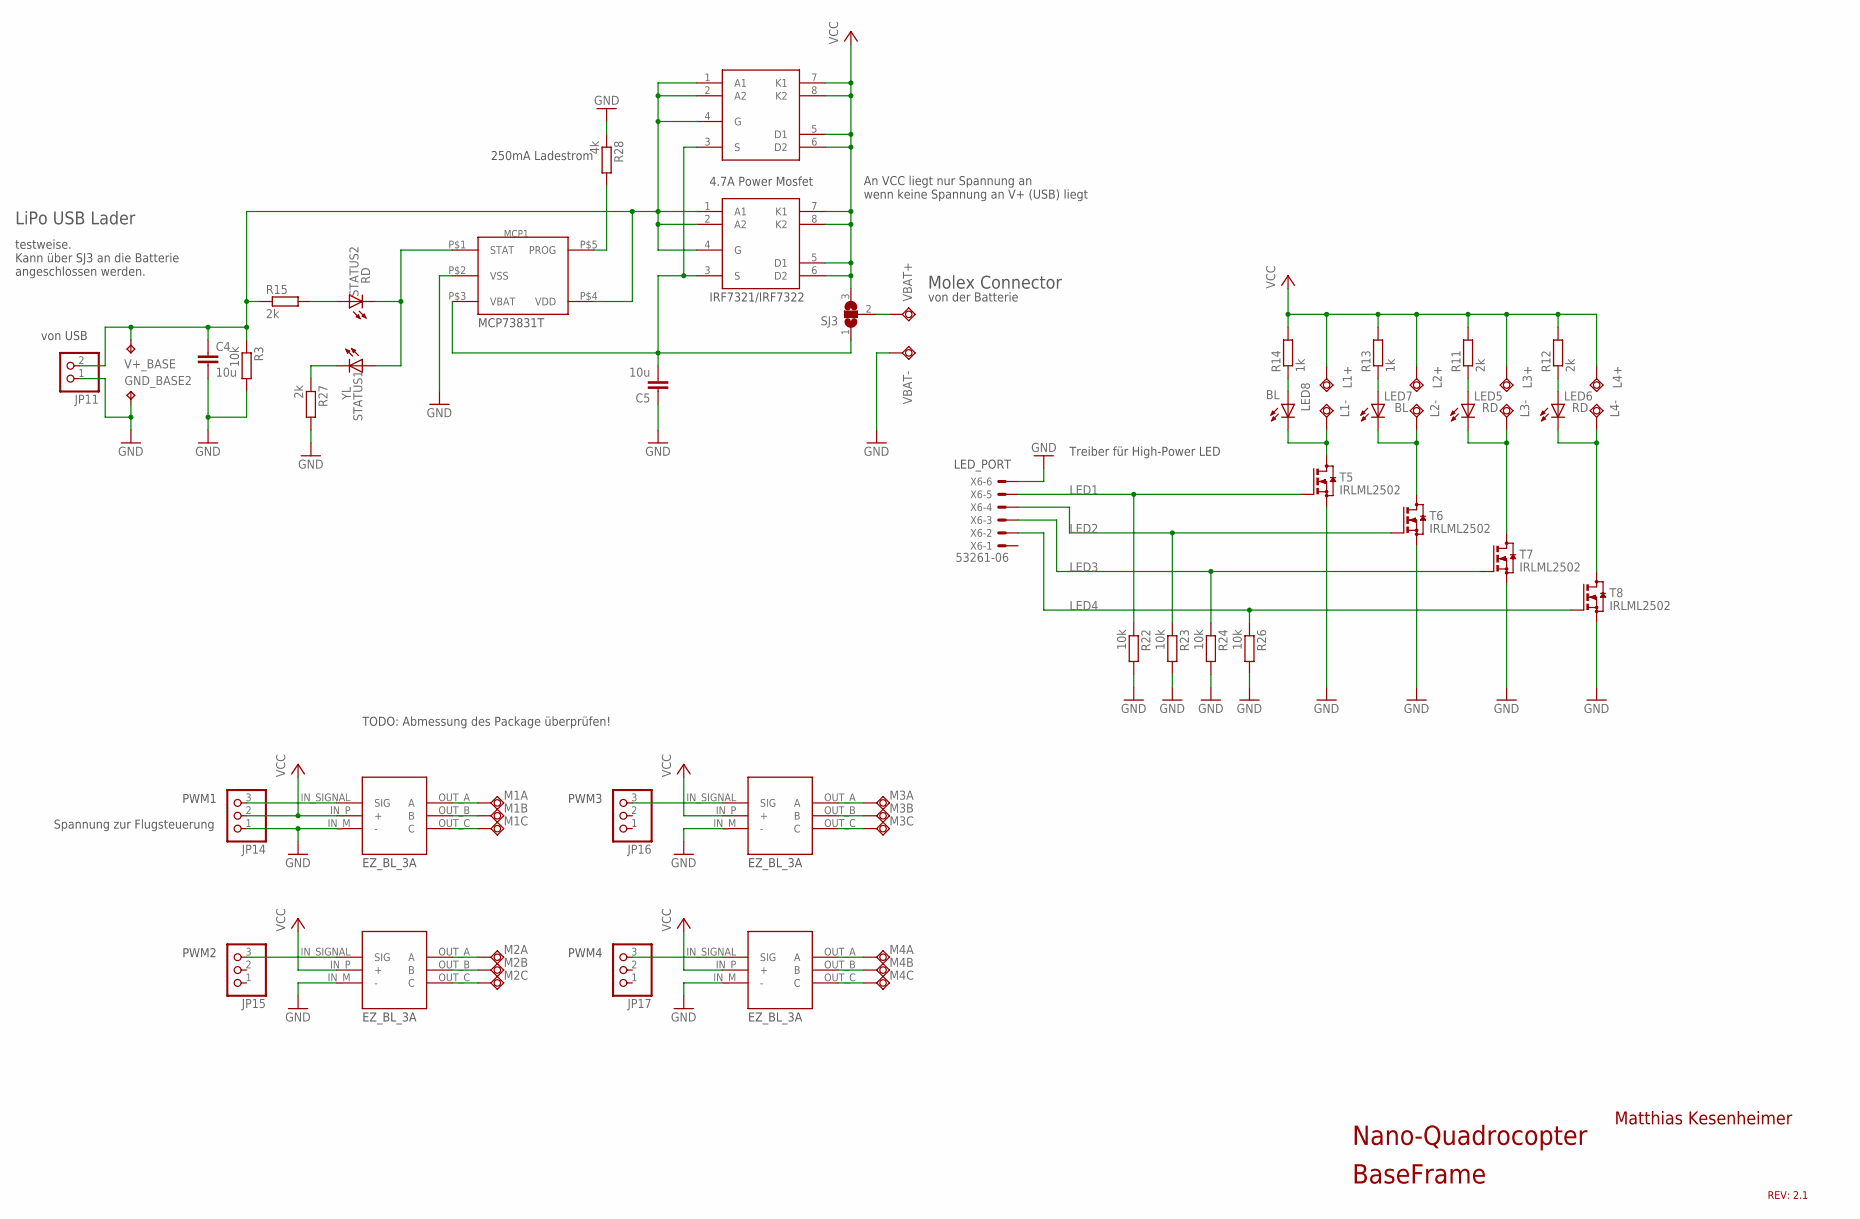
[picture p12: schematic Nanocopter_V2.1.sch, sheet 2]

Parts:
C4, C5: 10u; C1206
GND_BASE2: TPTP12SQ; TP12SQ
JP11: PINHD-1X2/90; 1X02/90
JP14, JP15, JP16, JP17: PINHD-1X3/90; 1X03/90
L1+, L1-, L2+, L2-, L3+, L3-, L4+, L4-: TPSQTP20SQ; TP20SQ
LED5, LED6: RD; CHIPLED_0603
LED7, LED8: BL; CHIPLED_0603
M1A, M1B, M1C, M2A, M2B, M2C, M3A, M3B, M3C, M4A, M4B, M4C: TPSQTP20SQ; TP20SQ
MCP1: MCP73831; 5PIN_SOT23
R3, R22, R23, R24, R26: 10k; R0603
R11, R12, R15, R27: 2k; R0603
R13, R14: 1k; R0603
R28: 4k; R0603
SJ3: SJ2W; SJ_2
STATUS1: YL; CHIPLED_0603
STATUS2: RD; CHIPLED_0603
T5, T6, T7, T8: IRLML2502; SOT23
U$1, U$2, U$3, U$4: EAZY_BL_3A; EZ_BL_3A_P
U$5, U$6: IRF7321; SO8
V+_BASE: TPTP12SQ; TP12SQ
VBAT+: TPSQTP20SQ; TP20SQ
VBAT-: TPSQTP20SQ; TP20SQ
X6: 53261-06

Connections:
GND: C4.2, C5.1, GND_BASE2.TP, JP11.1, JP14.1, MCP1.P$2 (VSS), R3.2, R22.2, R23.2, R24.2, R26.2, R27.2, R28.1, T5.2 (S), T6.2 (S), T7.2 (S), T8.2 (S), U$1.IN_M (-), U$2.IN_M (-), U$3.IN_M (-), U$4.IN_M (-), VBAT-.TP, X6.6; also elsewhere on the board
LED1: R22.1, T5.1 (G), X6.5
LED2: R23.1, T6.1 (G), X6.4
LED3: R24.1, T7.1 (G), X6.3
LED4: R26.1, T8.1 (G), X6.2
unnamed: LED5.A, R11.1
unnamed: LED6.A, R12.1
unnamed: LED7.A, R13.1
unnamed: L1-.TP, LED8.C, T5.3 (D)
unnamed: L3-.TP, LED5.C, T7.3 (D)
unnamed: L4-.TP, LED6.C, T8.3 (D)
unnamed: L2-.TP, LED7.C, T6.3 (D)
unnamed: MCP1.P$5 (PROG), R28.2
unnamed: JP14.3, U$1.IN_SIGNAL (SIG)
unnamed: M2A.TP, U$2.OUT_A (A)
unnamed: LED8.A, R14.1
unnamed: C5.2, MCP1.P$3 (VBAT), SJ3.1, U$5.3 (S), U$6.3 (S)
unnamed: M2B.TP, U$2.OUT_B (B)
unnamed: M2C.TP, U$2.OUT_C (C)
unnamed: R15.2, STATUS2.A
unnamed: M1A.TP, U$1.OUT_A (A)
unnamed: M1B.TP, U$1.OUT_B (B)
unnamed: M1C.TP, U$1.OUT_C (C)
unnamed: JP15.3, U$2.IN_SIGNAL (SIG)
unnamed: M3A.TP, U$3.OUT_A (A)
unnamed: M3B.TP, U$3.OUT_B (B)
unnamed: M3C.TP, U$3.OUT_C (C)
unnamed: JP16.3, U$3.IN_SIGNAL (SIG)
unnamed: M4A.TP, U$4.OUT_A (A)
unnamed: M4B.TP, U$4.OUT_B (B)
unnamed: M4C.TP, U$4.OUT_C (C)
unnamed: JP17.3, U$4.IN_SIGNAL (SIG)
unnamed: R27.1, STATUS1.C
unnamed: MCP1.P$1 (STAT), STATUS1.A, STATUS2.C
unnamed: SJ3.2, VBAT+.TP
VCC: JP14.2, L1+.TP, L2+.TP, L3+.TP, L4+.TP, R11.2, R12.2, R13.2, R14.2, SJ3.3, U$1.IN_P (+), U$2.IN_P (+), U$3.IN_P (+), U$4.IN_P (+), U$5.5 (D1), U$5.6 (D2), U$5.7 (K1), U$5.8 (K2), U$6.5 (D1), U$6.6 (D2), U$6.7 (K1), U$6.8 (K2); also elsewhere on the board
VDD: C4.1, JP11.2, MCP1.P$4 (VDD), R3.1, R15.1, U$5.1 (A1), U$5.2 (A2), U$5.4 (G), U$6.1 (A1), U$6.2 (A2), U$6.4 (G), V+_BASE.TP

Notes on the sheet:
LiPo USB Lader
250mA Ladestrom
Matthias Kesenheimer
REV: 2.1
Nano-Quadrocopter
BaseFrame
Treiber für High-Power LED
Molex Connector
PWM1
PWM2
PWM3
PWM4
Spannung zur Flugsteuerung
von der Batterie
von USB
LED_PORT
testweise. Kann über SJ3 an die Batterie angeschlossen werden.
4.7A Power Mosfet
IRF7321/IRF7322
MCP73831T
An VCC liegt nur Spannung an wenn keine Spannung an V+ (USB) liegt
TODO: Abmessung des Package überprüfen!
EZ_BL_3A

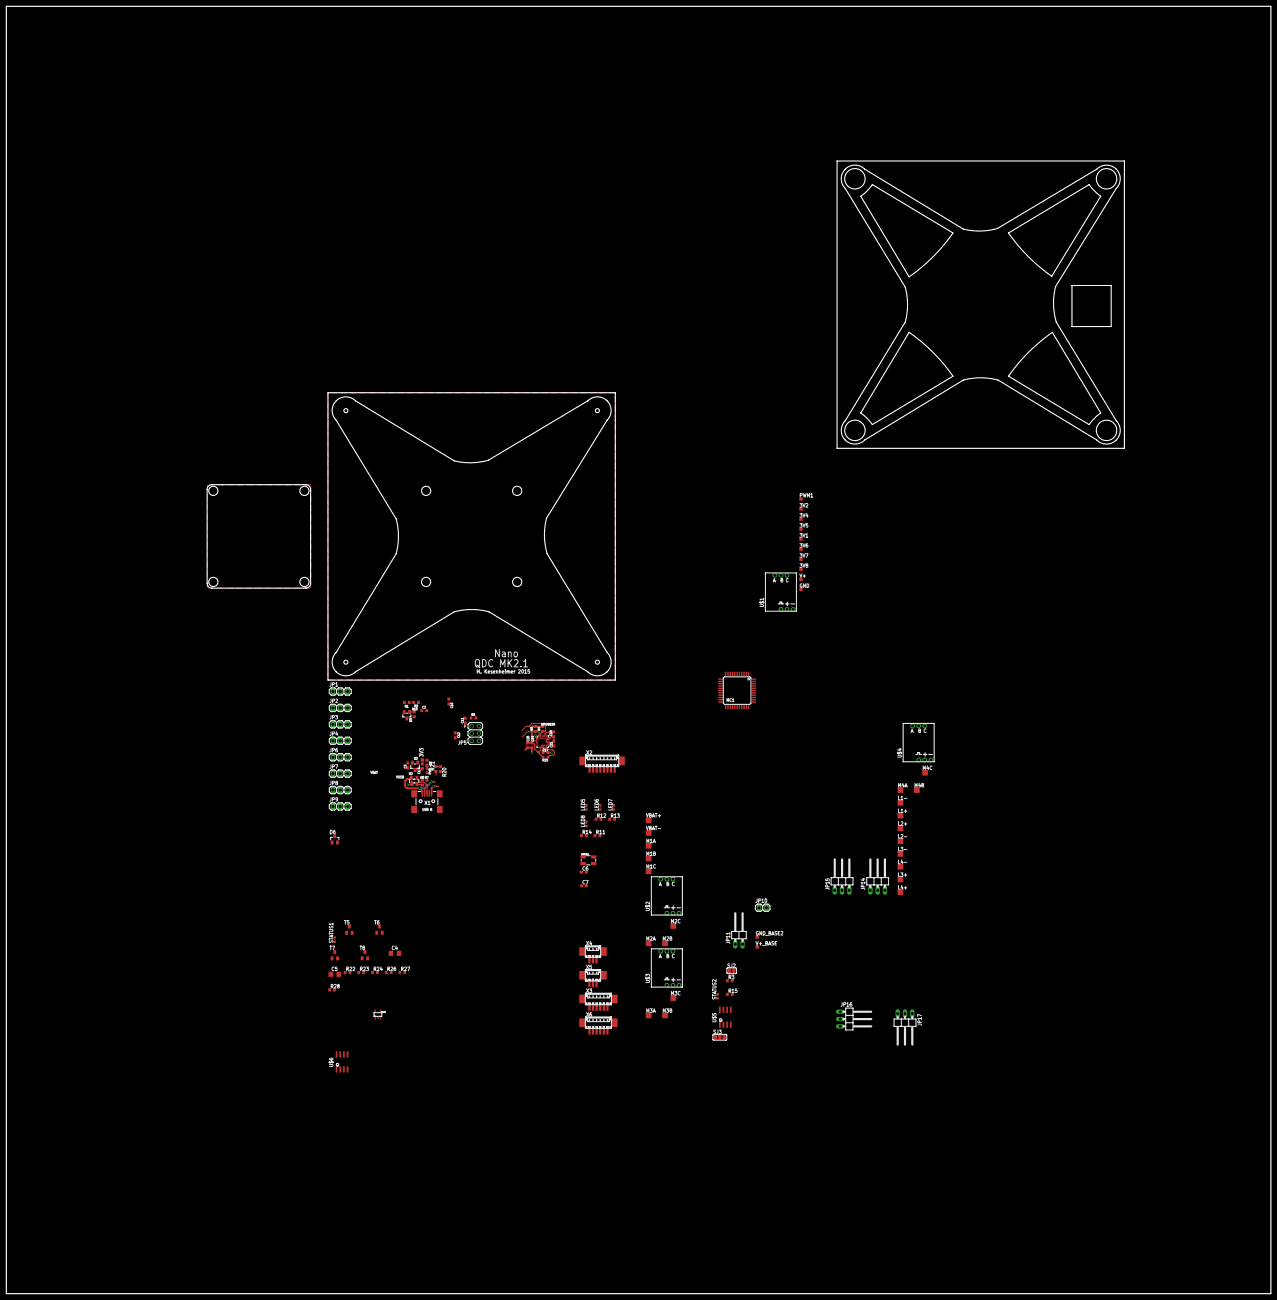
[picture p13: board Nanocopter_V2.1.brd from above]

Board: 2 copper layers, 440.1 x 448.0 mm, 122 parts (0 on the bottom side), 79 nets.

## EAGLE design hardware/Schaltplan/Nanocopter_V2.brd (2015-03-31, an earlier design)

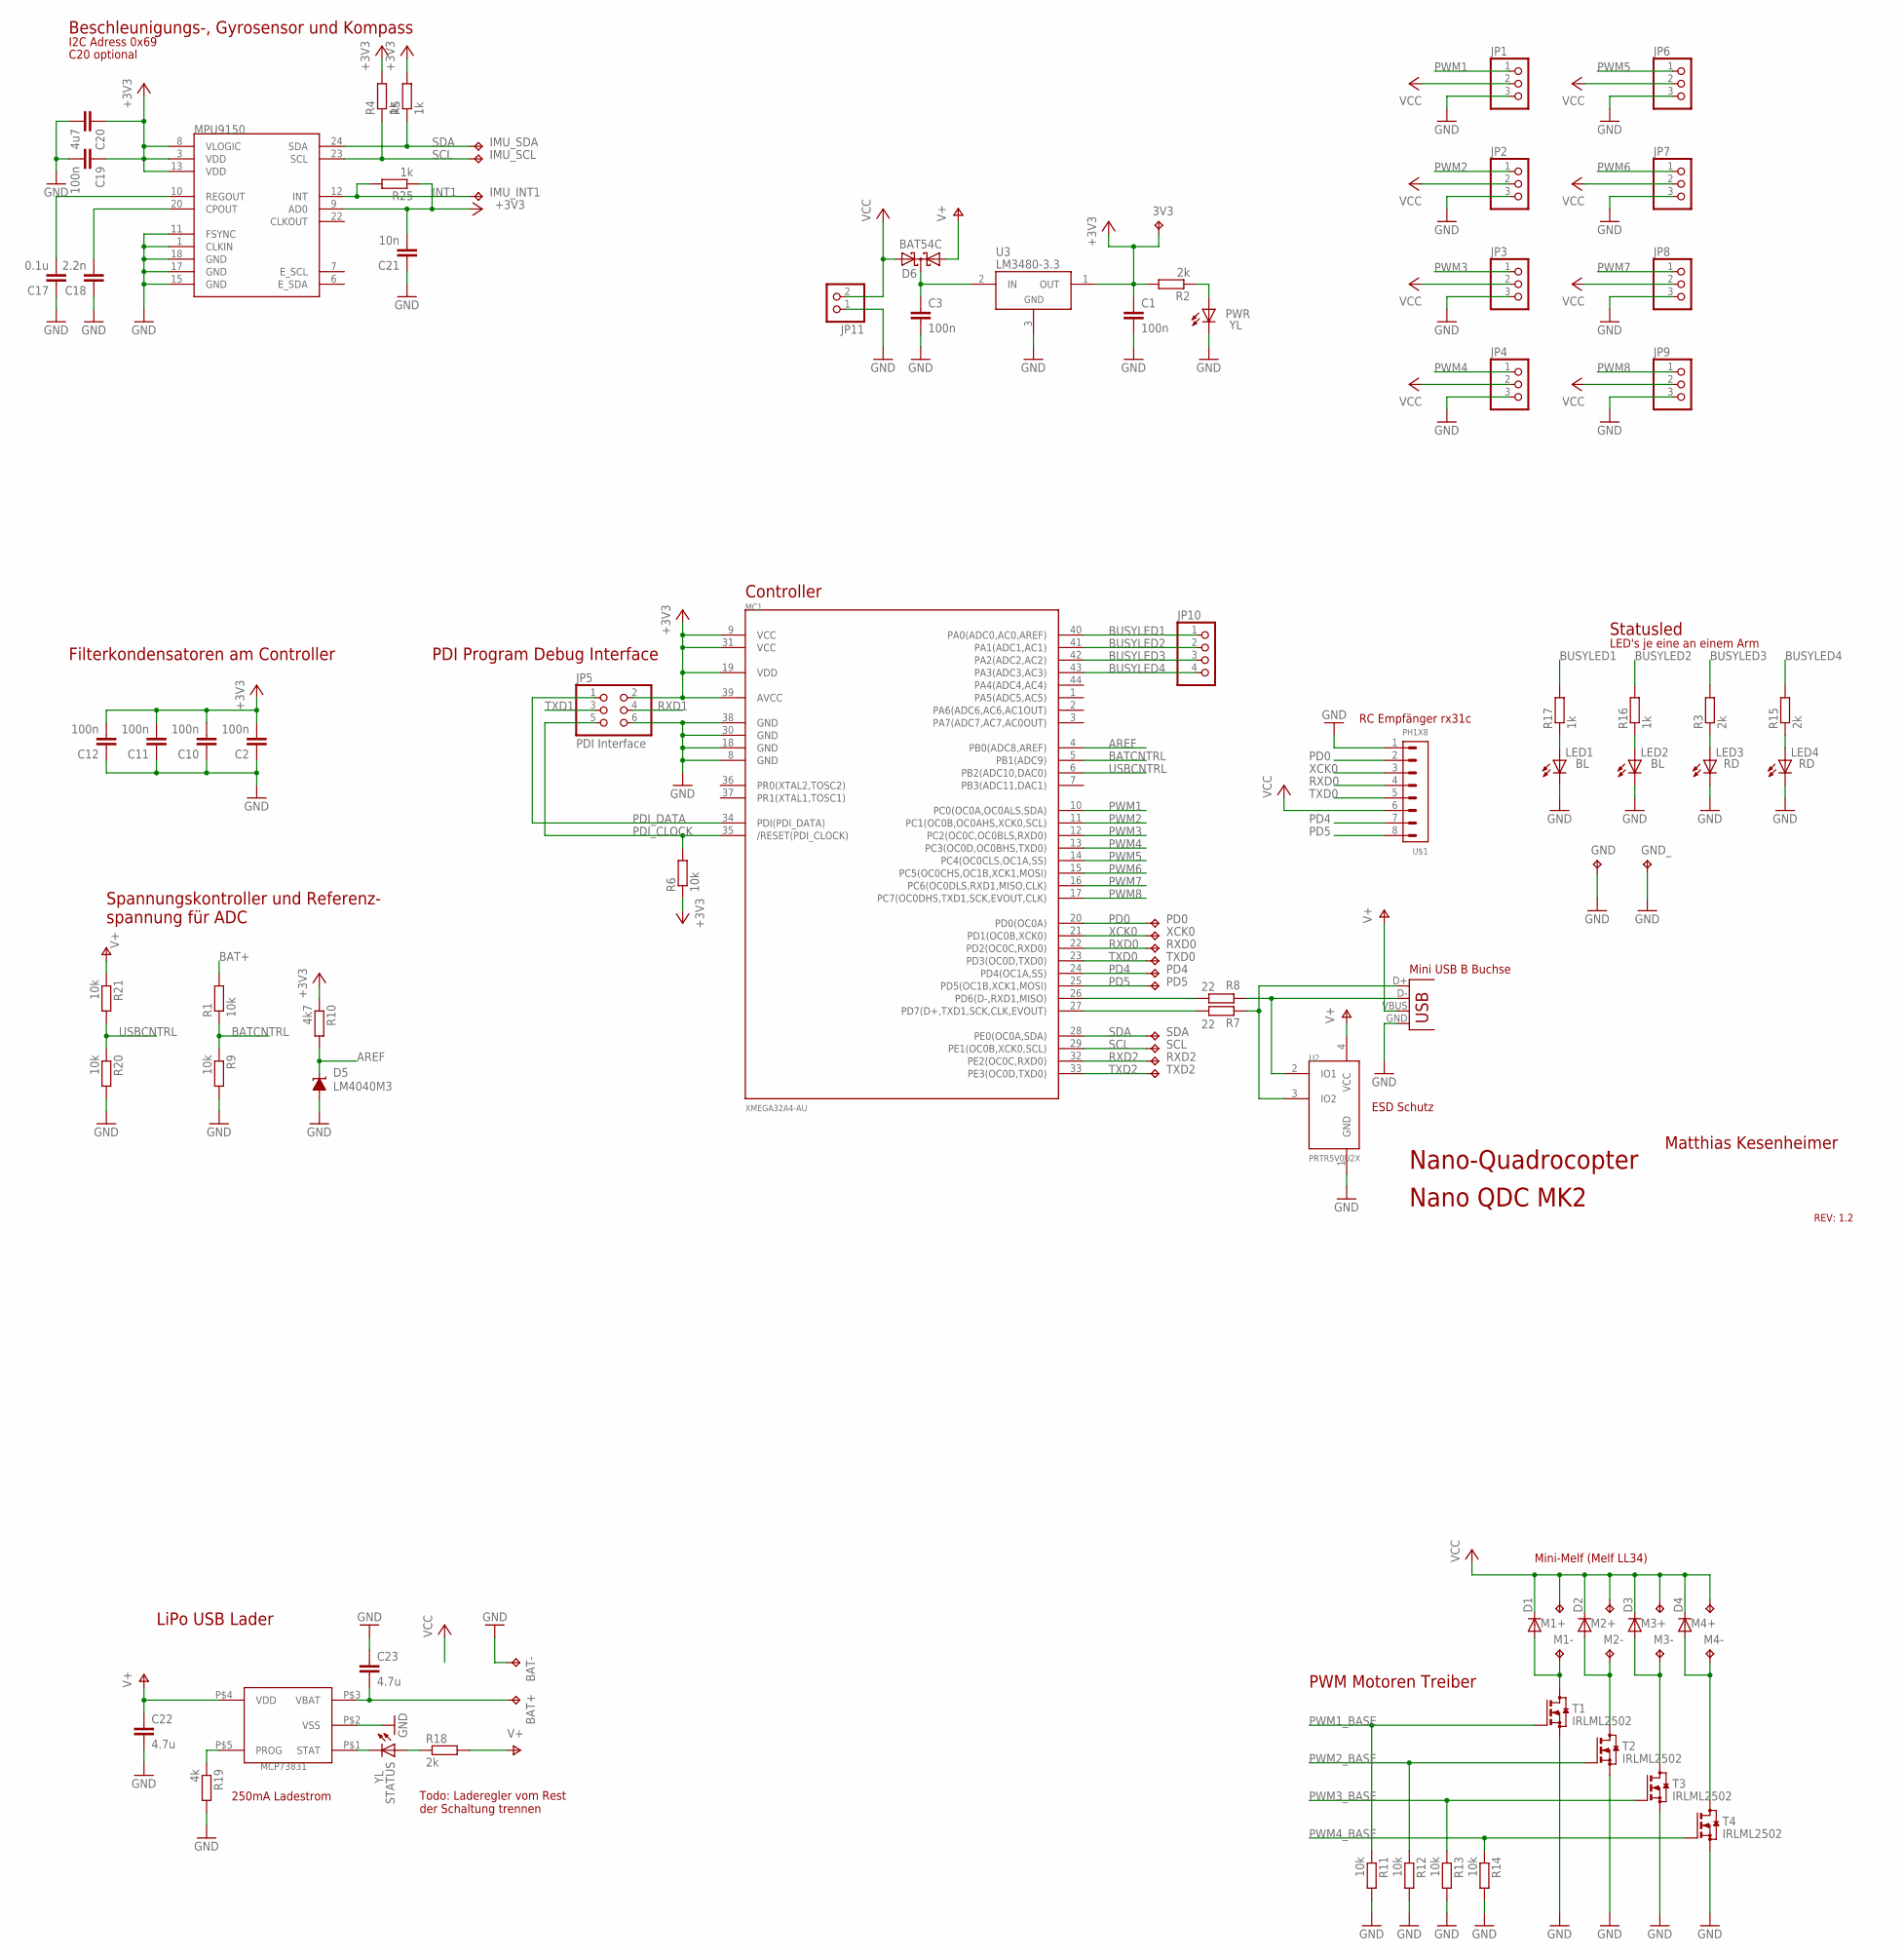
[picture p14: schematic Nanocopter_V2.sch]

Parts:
3V3: TPTP12SQ; TP12SQ
BAT+: TPTP12SQ; TP12SQ
BAT-: TPTP12SQ; TP12SQ
C1, C2, C3, C10, C11, C12, C19: 100n; C0603
C17: 0.1u; C0603
C18: 2.2n; C0603
C20: 4u7; C0603
C21: 10n; C0603
C22, C23: 4.7u; C1206
D1, D2, D3, D4: DIODE-MINIMELF; MINIMELF
D5: LM4040M3; SOT-23
D6: BAT54C; SOT23
GND: TPTP12SQ; TP12SQ
GND_: TPTP12SQ; TP12SQ
IMU_INT1: TPTP10SQ; TP10SQ
IMU_SCL: TPTP10SQ; TP10SQ
IMU_SDA: TPTP10SQ; TP10SQ
JP1, JP2, JP3, JP4, JP6, JP7, JP8, JP9: PINHD-1X3; 1X03
JP5: PDI Interface; 2X03
JP10: PINHD-1X4; 1X04
JP11: PINHD-1X2; 1X02
LED1, LED2: BL; CHIPLED_0603
LED3, LED4: RD; CHIPLED_0603
M1+, M1-, M2+, M2-, M3+, M3-, M4+, M4-: TPTP15SQ; TP15SQ
MC1: XMEGA32A4-AU; TQFP44
MCP73831: MCP73831; 5PIN_SOT23
MPU9150: MPU-9150QFN-24-NP; QFN-24-NP
PD0, PD4, PD5: TPTP10SQ; TP10SQ
PWR: YL; CHIPLED_0603
R1, R6, R9, R11, R12, R13, R14, R20, R21: 10k; R0603
R2, R3, R15, R18: 2k; R0603
R4, R5, R16, R17, R25: 1k; R0603
R7, R8: 22; R0603
R10: 4k7; R0603
R19: 4k; R0603
RXD0, RXD2: TPTP10SQ; TP10SQ
SCL: TPTP10SQ; TP10SQ
SDA: TPTP10SQ; TP10SQ
STATUS: YL; CHIPLED_0603
T1, T2, T3, T4: IRLML2502; SOT23
TXD0, TXD2: TPTP10SQ; TP10SQ
U2: PRTR5V0U2X; SOT143B
U3: LM3480-3.3; SOT-23-3
U$1: PH1X8; PHL005-1-8
X1: USBSMD; USB-MINIB
XCK0: TPTP10SQ; TP10SQ

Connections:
+3V3: 3V3.TP, C1.1, C2.2, C10.2, C11.2, C12.2, C19.1, C20.1, C21.2, JP5.2, MC1.9 (VCC), MC1.19 (VDD), MC1.31 (VCC), MC1.39 (AVCC), MPU9150.3 (VDD), MPU9150.8 (VLOGIC), MPU9150.9 (AD0), MPU9150.13 (VDD), R2.2, R4.2, R5.2, R6.1, R10.1, R25.1, U3.1 (OUT)
AREF: D5.1 (C), MC1.4 (PB0(ADC8,AREF)), R10.2
BAT+: BAT+.TP, C23.2, MCP73831.P$3 (VBAT), R1.2
BATCNTRL: MC1.5 (PB1(ADC9)), R1.1, R9.1
BUSYLED1: JP10.1, MC1.40 (PA0(ADC0,AC0,AREF)), R17.2
BUSYLED2: JP10.2, MC1.41 (PA1(ADC1,AC1)), R16.2
BUSYLED3: JP10.3, MC1.42 (PA2(ADC2,AC2)), R3.2
BUSYLED4: JP10.4, MC1.43 (PA3(ADC3,AC3)), R15.2
GND: BAT-.TP, C1.2, C2.1, C3.2, C10.1, C11.1, C12.1, C17.1, C18.1, C19.2, C20.2, C21.1, C22.2, C23.1, D5.2 (A), GND.TP, GND_.TP, JP1.3, JP2.3, JP3.3, JP4.3, JP5.6, JP6.3, JP7.3, JP8.3, JP9.3, JP11.1, LED1.C, LED2.C, LED3.C, LED4.C, MC1.8 (GND), MC1.18 (GND), MC1.30 (GND), MC1.38 (GND), MCP73831.P$2 (VSS), MPU9150.1 (CLKIN), MPU9150.11 (FSYNC), MPU9150.15 (GND), MPU9150.17 (GND), MPU9150.18 (GND), PWR.C, R9.2, R11.2, R12.2, R13.2, R14.2, R19.2, R20.2, T1.2 (S), T2.2 (S), T3.2 (S), T4.2 (S), U2.1 (GND), U3.3 (GND), U$1.1, X1.GND
INT1: IMU_INT1.TP, MPU9150.12 (INT), R25.2
unnamed: C18.2, MPU9150.20 (CPOUT)
unnamed: MCP73831.P$1 (STAT), STATUS.C
unnamed: R18.1, STATUS.A
unnamed: MCP73831.P$5 (PROG), R19.1
unnamed: C17.2, MPU9150.10 (REGOUT)
unnamed: C3.1, D6.3 (CC), U3.2 (IN)
unnamed: PWR.A, R2.1
unnamed: LED3.A, R3.1
unnamed: LED4.A, R15.1
unnamed: LED2.A, R16.1
unnamed: LED1.A, R17.1
unnamed: D1.A, M1-.TP, T1.3 (D)
unnamed: D3.A, M3-.TP, T3.3 (D)
unnamed: D4.A, M4-.TP, T4.3 (D)
unnamed: D2.A, M2-.TP, T2.3 (D)
PD0: MC1.20 (PD0(OC0A)), PD0.TP, U$1.2
PD4: MC1.24 (PD4(OC1A,SS)), PD4.TP, U$1.7
PD5: MC1.25 (PD5(OC1B,XCK1,MOSI)), PD5.TP, U$1.8
PDI_CLOCK: JP5.5, MC1.35 (/RESET(PDI_CLOCK)), R6.2
PDI_DATA: JP5.1, MC1.34 (PDI(PDI_DATA))
PWM1: JP1.1, MC1.10 (PC0(OC0A,OC0ALS,SDA))
PWM1_BASE: R11.1, T1.1 (G)
PWM2: JP2.1, MC1.11 (PC1(OC0B,OC0AHS,XCK0,SCL))
PWM2_BASE: R12.1, T2.1 (G)
PWM3: JP3.1, MC1.12 (PC2(OC0C,OC0BLS,RXD0))
PWM3_BASE: R13.1, T3.1 (G)
PWM4: JP4.1, MC1.13 (PC3(OC0D,OC0BHS,TXD0))
PWM4_BASE: R14.1, T4.1 (G)
PWM5: JP6.1, MC1.14 (PC4(OC0CLS,OC1A,SS))
PWM6: JP7.1, MC1.15 (PC5(OC0CHS,OC1B,XCK1,MOSI))
PWM7: JP8.1, MC1.16 (PC6(OC0DLS,RXD1,MISO,CLK))
PWM8: JP9.1, MC1.17 (PC7(OC0DHS,TXD1,SCK,EVOUT,CLK))
RXD0: MC1.22 (PD2(OC0C,RXD0)), RXD0.TP, U$1.4
RXD1: JP5.4, MC1.26 (PD6(D-,RXD1,MISO)), R8.2
RXD2: MC1.32 (PE2(OC0C,RXD0)), RXD2.TP
SCL: IMU_SCL.TP, MC1.29 (PE1(OC0B,XCK0,SCL)), MPU9150.23 (SCL), R4.1, SCL.TP
SDA: IMU_SDA.TP, MC1.28 (PE0(OC0A,SDA)), MPU9150.24 (SDA), R5.1, SDA.TP
TXD0: MC1.23 (PD3(OC0D,TXD0)), TXD0.TP, U$1.5
TXD1: JP5.3, MC1.27 (PD7(D+,TXD1,SCK,CLK,EVOUT)), R7.2
TXD2: MC1.33 (PE3(OC0D,TXD0)), TXD2.TP
USB+: R7.1, U2.3 (IO2), X1.D+
USB-: R8.1, U2.2 (IO1), X1.D-
USBCNTRL: MC1.6 (PB2(ADC10,DAC0)), R20.1, R21.2
V+: D6.1 (A1), R18.2, R21.1, U2.4 (VCC), X1.VBUS
VCC: D1.C, D2.C, D3.C, D4.C, D6.2 (A2), JP1.2, JP2.2, JP3.2, JP4.2, JP6.2, JP7.2, JP8.2, JP9.2, JP11.2, M1+.TP, M2+.TP, M3+.TP, M4+.TP, U$1.6
VDD: C22.1, MCP73831.P$4 (VDD)
XCK0: MC1.21 (PD1(OC0B,XCK0)), U$1.3, XCK0.TP

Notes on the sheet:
I2C Adress 0x69
Beschleunigungs-, Gyrosensor und Kompass
PWM Motoren Treiber
Statusled
PDI Program Debug Interface
Matthias Kesenheimer
REV: 1.2
Nano-Quadrocopter
Nano QDC MK2
Mini USB B Buchse
Controller
Filterkondensatoren am Controller
C20 optional
Spannungskontroller und Referenz- spannung für ADC
LED's je eine an einem Arm
ESD Schutz
RC Empfänger rx31c
Mini-Melf (Melf LL34)
LiPo USB Lader
250mA Ladestrom
Todo: Laderegler vom Rest der Schaltung trennen

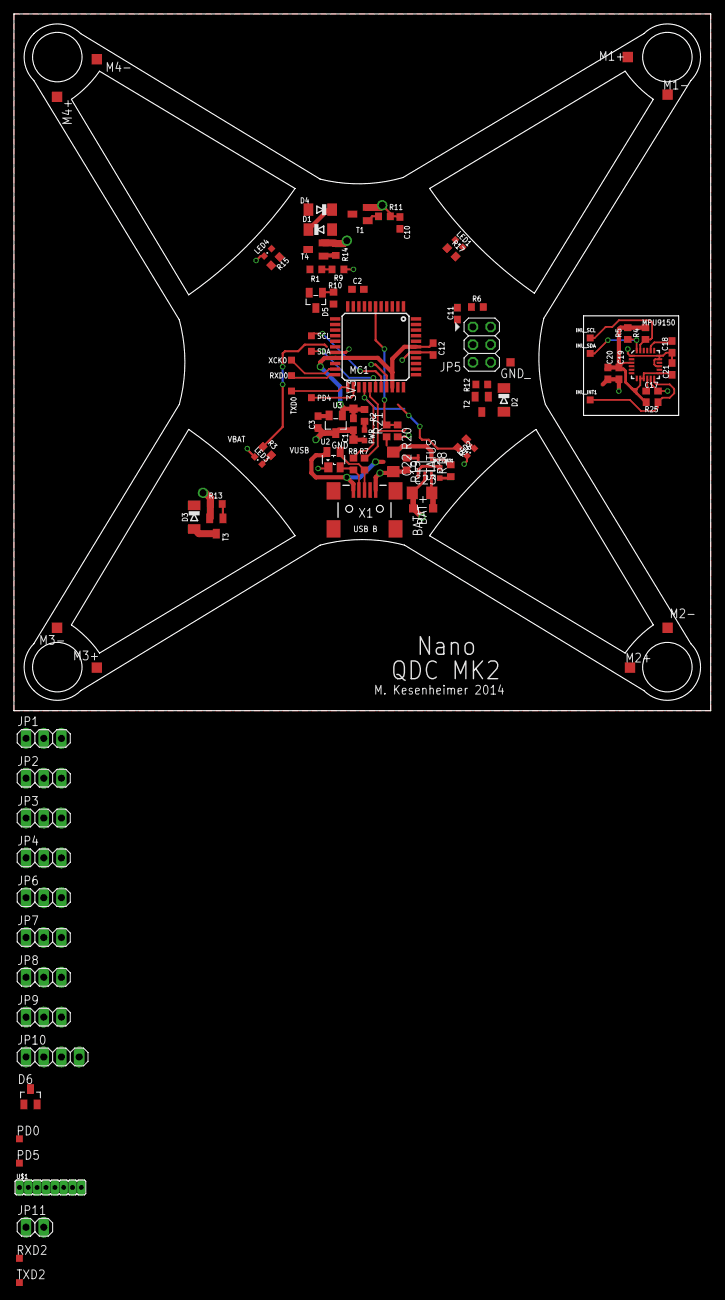
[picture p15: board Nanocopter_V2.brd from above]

Board: 2 copper layers, 100.0 x 100.0 mm, 95 parts (0 on the bottom side), 57 nets.

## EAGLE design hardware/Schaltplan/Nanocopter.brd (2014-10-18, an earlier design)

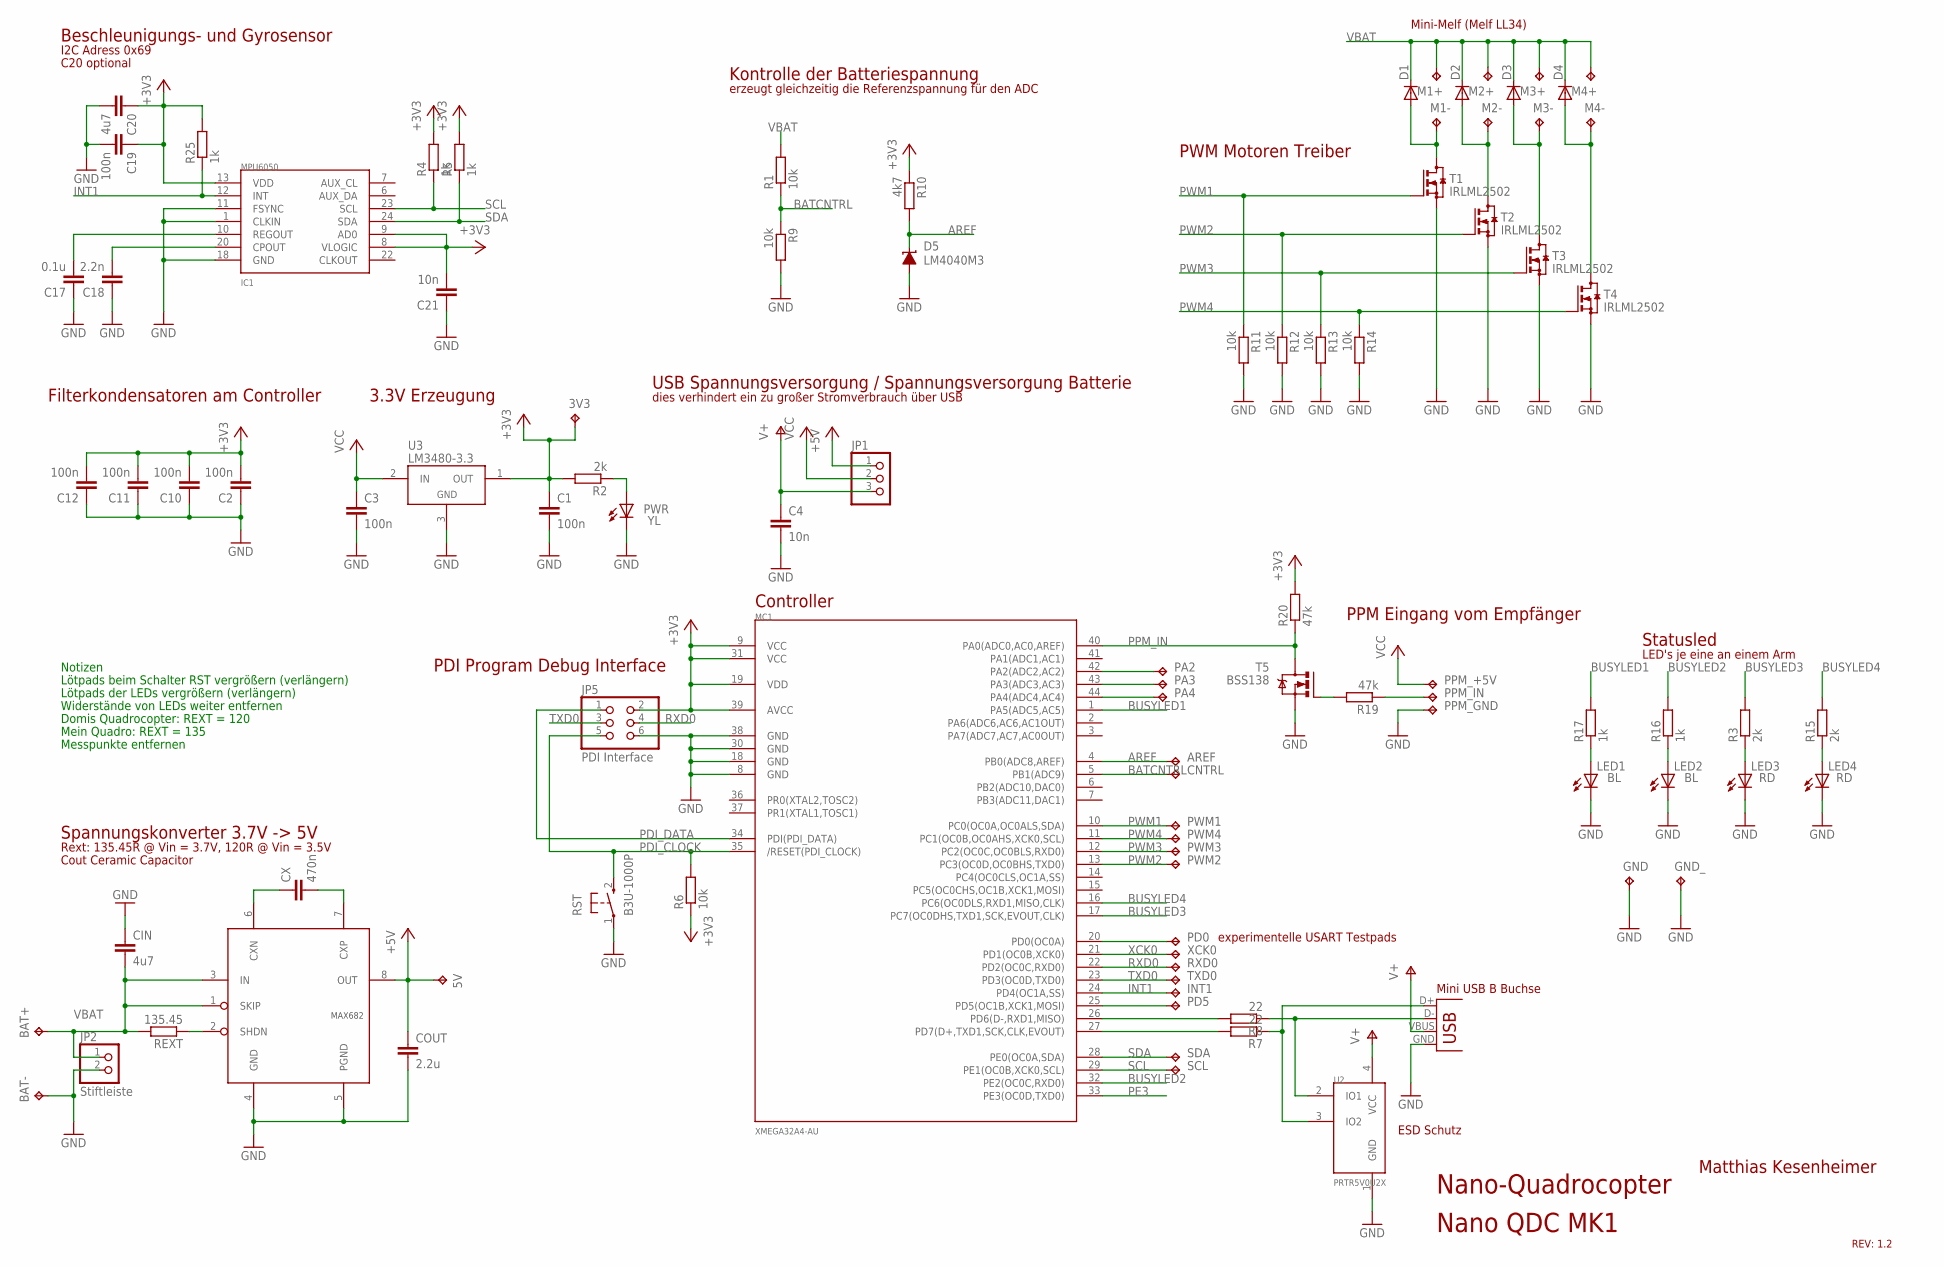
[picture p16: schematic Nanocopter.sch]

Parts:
3V3, 5V: TPTP12SQ; TP12SQ
AREF: TPTP10SQ; TP10SQ
BAT+: TPTP12SQ; TP12SQ
BAT-: TPTP12SQ; TP12SQ
C1, C2, C3, C10, C11, C12, C19: 100n; C0603
C4, C21: 10n; C0603
C17: 0.1u; C0603
C18: 2.2n; C0603
C20: 4u7; C0603
CIN: 4u7; C1206
CNTRL: TPTP10SQ; TP10SQ
COUT: 2.2u; C1206
CX: 470n; C0603
D1, D2, D3, D4: DIODE-MINIMELF; MINIMELF
D5: LM4040M3; SOT-23
GND: TPTP12SQ; TP12SQ
GND_: TPTP12SQ; TP12SQ
IC1: MPU6050; QFN-24
INT1: TPTP10SQ; TP10SQ
JP1: PINHD-1X3; 1X03
JP2: Stiftleiste; 1X02
JP5: PDI Interface; 2X03
LED1, LED2: BL; CHIPLED_0603
LED3, LED4: RD; CHIPLED_0603
M1+, M1-, M2+, M2-, M3+, M3-, M4+, M4-: TPTP15SQ; TP15SQ
MC1: XMEGA32A4-AU; TQFP44
PA2, PA3, PA4: TPTP10SQ; TP10SQ
PD0, PD5: TPTP10SQ; TP10SQ
PPM_+5V: TPTP10SQ; TP10SQ
PPM_GND: TPTP10SQ; TP10SQ
PPM_IN: TPTP10SQ; TP10SQ
PWM1, PWM2, PWM3, PWM4: TPTP10SQ; TP10SQ
PWR: YL; CHIPLED_0603
R1, R6, R9, R11, R12, R13, R14: 10k; R0603
R2, R3, R15: 2k; R0603
R4, R5, R16, R17, R25: 1k; R0603
R7, R8: 22; R0603
R10: 4k7; R0603
R19, R20: 47k; R0603
REXT: 135.45; R0603
RST: B3U-1000P; SW_SMD
RXD0: TPTP10SQ; TP10SQ
SCL: TPTP10SQ; TP10SQ
SDA: TPTP10SQ; TP10SQ
T1, T2, T3, T4: IRLML2502; SOT23
T5: BSS138; SOT23
TXD0: TPTP10SQ; TP10SQ
U1: MAX682; SOIC(N)8
U2: PRTR5V0U2X; SOT143B
U3: LM3480-3.3; SOT-23-3
X1: USBSMD; USB-MINIB
XCK0: TPTP10SQ; TP10SQ

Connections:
+3V3: 3V3.TP, C1.1, C2.2, C10.2, C11.2, C12.2, C19.1, C20.1, C21.2, IC1.8 (VLOGIC), IC1.9 (AD0), IC1.13 (VDD), JP5.2, MC1.9 (VCC), MC1.19 (VDD), MC1.31 (VCC), MC1.39 (AVCC), R2.2, R4.2, R5.2, R6.1, R10.1, R20.2, R25.2, U3.1 (OUT)
+5V: 5V.TP, COUT.1, JP1.1, U1.8 (OUT)
AREF: AREF.TP, D5.1 (C), MC1.4 (PB0(ADC8,AREF)), R10.2
BATCNTRL: CNTRL.TP, MC1.5 (PB1(ADC9)), R1.1, R9.1
BUSYLED1: MC1.1 (PA5(ADC5,AC5)), R17.2
BUSYLED2: MC1.32 (PE2(OC0C,RXD0)), R16.2
BUSYLED3: MC1.17 (PC7(OC0DHS,TXD1,SCK,EVOUT,CLK)), R3.2
BUSYLED4: MC1.16 (PC6(OC0DLS,RXD1,MISO,CLK)), R15.2
D+: MC1.27 (PD7(D+,TXD1,SCK,CLK,EVOUT)), R7.2
D-: MC1.26 (PD6(D-,RXD1,MISO)), R8.2
GND: BAT-.TP, C1.2, C2.1, C3.2, C4.2, C10.1, C11.1, C12.1, C17.1, C18.1, C19.2, C20.2, C21.1, CIN.1, COUT.2, D5.2 (A), GND.TP, GND_.TP, IC1.1 (CLKIN), IC1.11 (FSYNC), IC1.18 (GND), JP2.2, JP5.6, LED1.C, LED2.C, LED3.C, LED4.C, MC1.8 (GND), MC1.18 (GND), MC1.30 (GND), MC1.38 (GND), PPM_GND.TP, PWR.C, R9.2, R11.2, R12.2, R13.2, R14.2, RST.1, T1.2 (S), T2.2 (S), T3.2 (S), T4.2 (S), T5.2 (S), U1.4 (GND), U1.5 (PGND), U2.1 (GND), U3.3 (GND), X1.GND
INT1: IC1.12 (INT), INT1.TP, MC1.24 (PD4(OC1A,SS)), R25.1
unnamed: R19.2, T5.1 (G)
unnamed: PPM_IN.TP, R19.1
unnamed: MC1.44 (PA4(ADC4,AC4)), PA4.TP
unnamed: CX.1, U1.6 (CXN)
unnamed: MC1.43 (PA3(ADC3,AC3)), PA3.TP
unnamed: MC1.42 (PA2(ADC2,AC2)), PA2.TP
unnamed: PWR.A, R2.1
unnamed: LED3.A, R3.1
unnamed: REXT.1, U1.2 (SHDN)
unnamed: CX.2, U1.7 (CXP)
unnamed: LED4.A, R15.1
unnamed: LED2.A, R16.1
unnamed: LED1.A, R17.1
unnamed: D1.A, M1-.TP, T1.3 (D)
unnamed: D3.A, M3-.TP, T3.3 (D)
unnamed: D4.A, M4-.TP, T4.3 (D)
unnamed: C17.2, IC1.10 (REGOUT)
unnamed: C18.2, IC1.20 (CPOUT)
unnamed: D2.A, M2-.TP, T2.3 (D)
unnamed: MC1.20 (PD0(OC0A)), PD0.TP
unnamed: MC1.25 (PD5(OC1B,XCK1,MOSI)), PD5.TP
PDI_CLOCK: JP5.5, MC1.35 (/RESET(PDI_CLOCK)), R6.2, RST.2
PDI_DATA: JP5.1, MC1.34 (PDI(PDI_DATA))
PE3: MC1.33 (PE3(OC0D,TXD0))
PPM_IN: MC1.40 (PA0(ADC0,AC0,AREF)), R20.1, T5.3 (D)
PWM1: MC1.10 (PC0(OC0A,OC0ALS,SDA)), PWM1.TP, R11.1, T1.1 (G)
PWM2: MC1.13 (PC3(OC0D,OC0BHS,TXD0)), PWM2.TP, R12.1, T2.1 (G)
PWM3: MC1.12 (PC2(OC0C,OC0BLS,RXD0)), PWM3.TP, R13.1, T3.1 (G)
PWM4: MC1.11 (PC1(OC0B,OC0AHS,XCK0,SCL)), PWM4.TP, R14.1, T4.1 (G)
RXD0: JP5.4, MC1.22 (PD2(OC0C,RXD0)), RXD0.TP
SCL: IC1.23 (SCL), MC1.29 (PE1(OC0B,XCK0,SCL)), R4.1, SCL.TP
SDA: IC1.24 (SDA), MC1.28 (PE0(OC0A,SDA)), R5.1, SDA.TP
TXD0: JP5.3, MC1.23 (PD3(OC0D,TXD0)), TXD0.TP
USB+: R7.1, U2.3 (IO2), X1.D+
USB-: R8.1, U2.2 (IO1), X1.D-
V+: C4.1, JP1.3, U2.4 (VCC), X1.VBUS
VBAT: BAT+.TP, CIN.2, D1.C, D2.C, D3.C, D4.C, JP2.1, M1+.TP, M2+.TP, M3+.TP, M4+.TP, R1.2, REXT.2, U1.1 (SKIP), U1.3 (IN)
VCC: C3.1, JP1.2, PPM_+5V.TP, U3.2 (IN)
XCK0: MC1.21 (PD1(OC0B,XCK0)), XCK0.TP

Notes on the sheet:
Rext: 135.45R @ Vin = 3.7V, 120R @ Vin = 3.5V
Cout Ceramic Capacitor
I2C Adress 0x69
Beschleunigungs- und Gyrosensor
PWM Motoren Treiber
PPM Eingang vom Empfänger
Spannungskonverter 3.7V -> 5V
USB Spannungsversorgung / Spannungsversorgung Batterie
3.3V Erzeugung
Statusled
PDI Program Debug Interface
Matthias Kesenheimer
REV: 1.2
Nano-Quadrocopter
Nano QDC MK1
Mini USB B Buchse
dies verhindert ein zu großer Stromverbrauch über USB
Controller
Filterkondensatoren am Controller
C20 optional
Kontrolle der Batteriespannung
erzeugt gleichzeitig die Referenzspannung für den ADC
LED's je eine an einem Arm
ESD Schutz
experimentelle USART Testpads
Mini-Melf (Melf LL34)
Notizen
Lötpads beim Schalter RST vergrößern (verlängern)
Lötpads der LEDs vergrößern (verlängern)
Widerstände von LEDs weiter entfernen
Domis Quadrocopter: REXT = 120
Mein Quadro: REXT = 135
Messpunkte entfernen

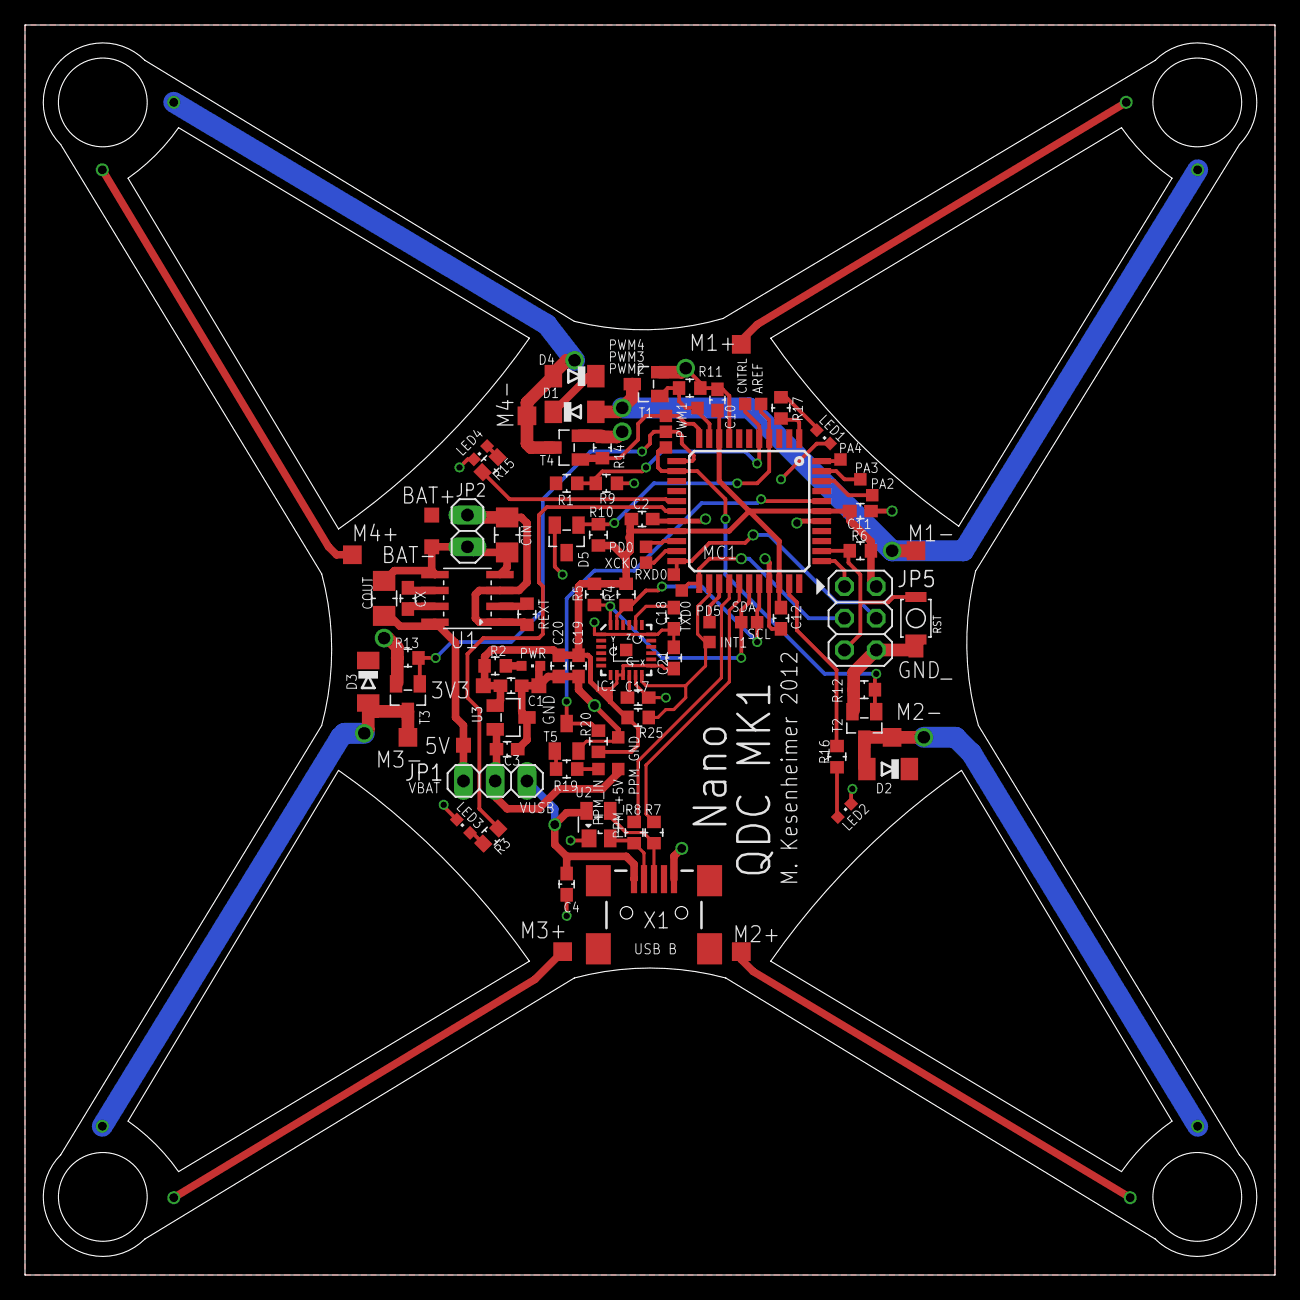
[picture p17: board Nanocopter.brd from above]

Board: 2 copper layers, 100.0 x 100.0 mm, 95 parts (0 on the bottom side), 50 nets.

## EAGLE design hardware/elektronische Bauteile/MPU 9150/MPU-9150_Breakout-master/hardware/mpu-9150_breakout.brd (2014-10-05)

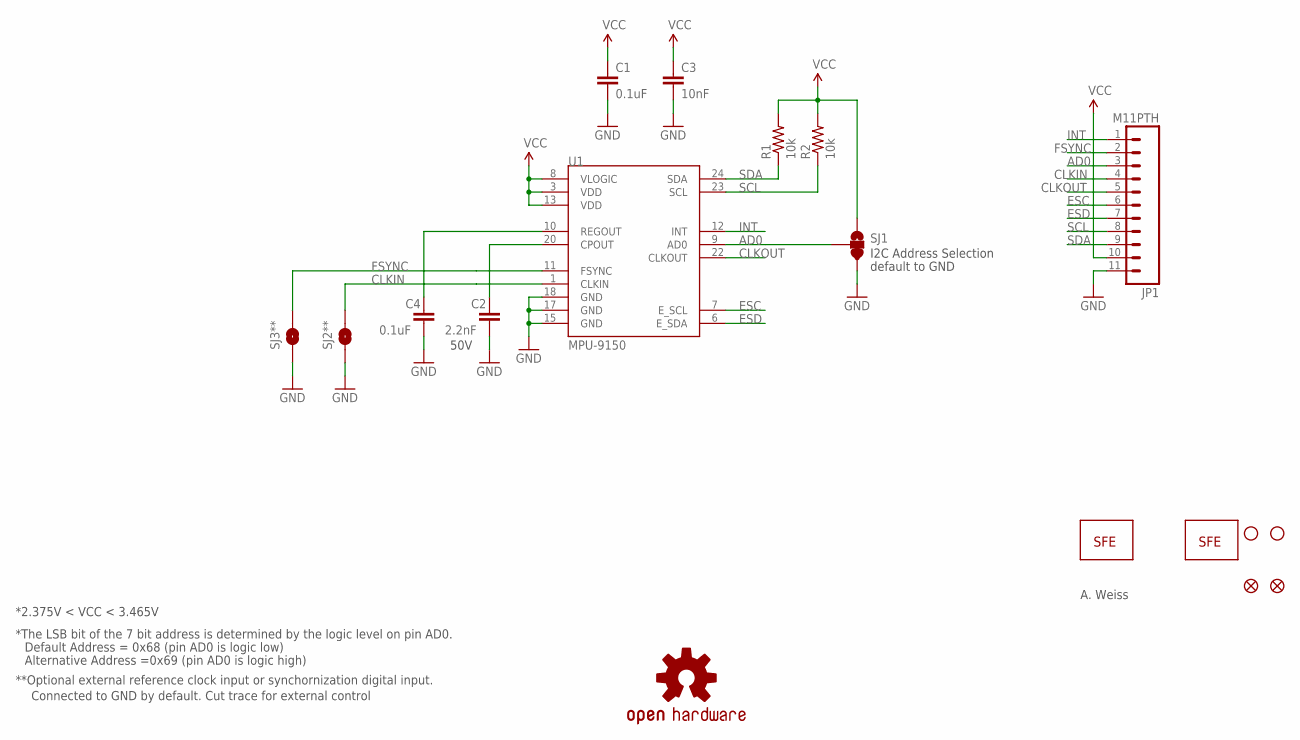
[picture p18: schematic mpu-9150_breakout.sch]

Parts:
C1, C4: 0.1uF; 0402-CAP
C2: 2.2nF; 0402-CAP
C3: 10nF; 0402-CAP
JP1: M11PTH; 1X11
JP2, JP3: STAND-OFF
JP4: LOGO-SFENW2; SFE-NEW-WEB
JP6: LOGO-SFESK; SFE-LOGO-FLAME
JP7, JP8: FIDUCIALUFIDUCIAL; MICRO-FIDUCIAL
R1, R2: 10k; 0402-RES
SJ1: SOLDERJUMPER_2WAYPASTE2&3; SJ_3_PASTE2&3
SJ2**, SJ3**: SOLDERJUMPERTRACE; SJ_2S-TRACE
U1: MPU-9150; QFN-24-NP
U$1: OSHW-LOGOS; OSHW-LOGO-S

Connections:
AD0: JP1.3, SJ1.2, U1.9 (AD0)
CLKIN: JP1.4, SJ2**.2, U1.1 (CLKIN)
CLKOUT: JP1.5, U1.22 (CLKOUT)
ESC: JP1.6, U1.7 (E_SCL)
ESD: JP1.7, U1.6 (E_SDA)
FSYNC: JP1.2, SJ3**.2, U1.11 (FSYNC)
GND: C1.2, C2.2, C3.2, C4.2, JP1.11, SJ1.3, SJ2**.1, SJ3**.1, U1.15 (GND), U1.17 (GND), U1.18 (GND)
INT: JP1.1, U1.12 (INT)
unnamed: C2.1, U1.20 (CPOUT)
unnamed: C4.1, U1.10 (REGOUT)
SCL: JP1.8, R2.1, U1.23 (SCL)
SDA: JP1.9, R1.1, U1.24 (SDA)
VCC: C1.1, C3.1, JP1.10, R1.2, R2.2, SJ1.1, U1.3 (VDD), U1.8 (VLOGIC), U1.13 (VDD)

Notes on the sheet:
50V
I2C Address Selection
**Optional external reference clock input or synchornization digital input.
Connected to GND by default. Cut trace for external control
Default Address = 0x68 (pin AD0 is logic low)
Alternative Address =0x69 (pin AD0 is logic high)
*The LSB bit of the 7 bit address is determined by the logic level on pin AD0.
default to GND
A. Weiss
*2.375V < VCC < 3.465V

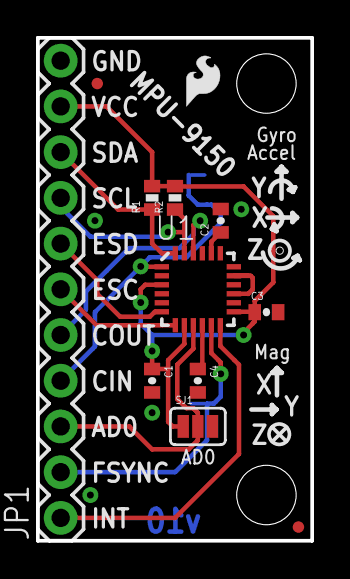
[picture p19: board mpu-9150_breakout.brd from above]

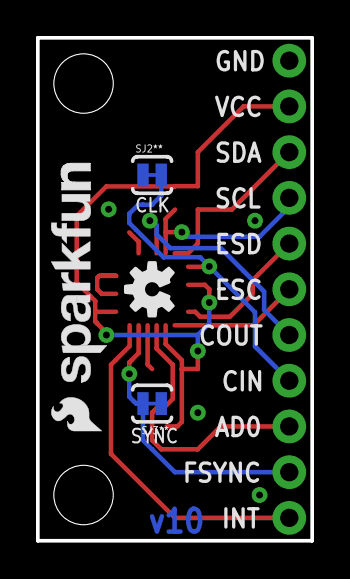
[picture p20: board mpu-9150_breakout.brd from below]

Board: 2 copper layers, 15.2 x 27.9 mm, 19 parts (5 on the bottom side), 13 nets.

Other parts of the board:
JP5: LOGO-SFESK; SFE-LOGO-FLAME

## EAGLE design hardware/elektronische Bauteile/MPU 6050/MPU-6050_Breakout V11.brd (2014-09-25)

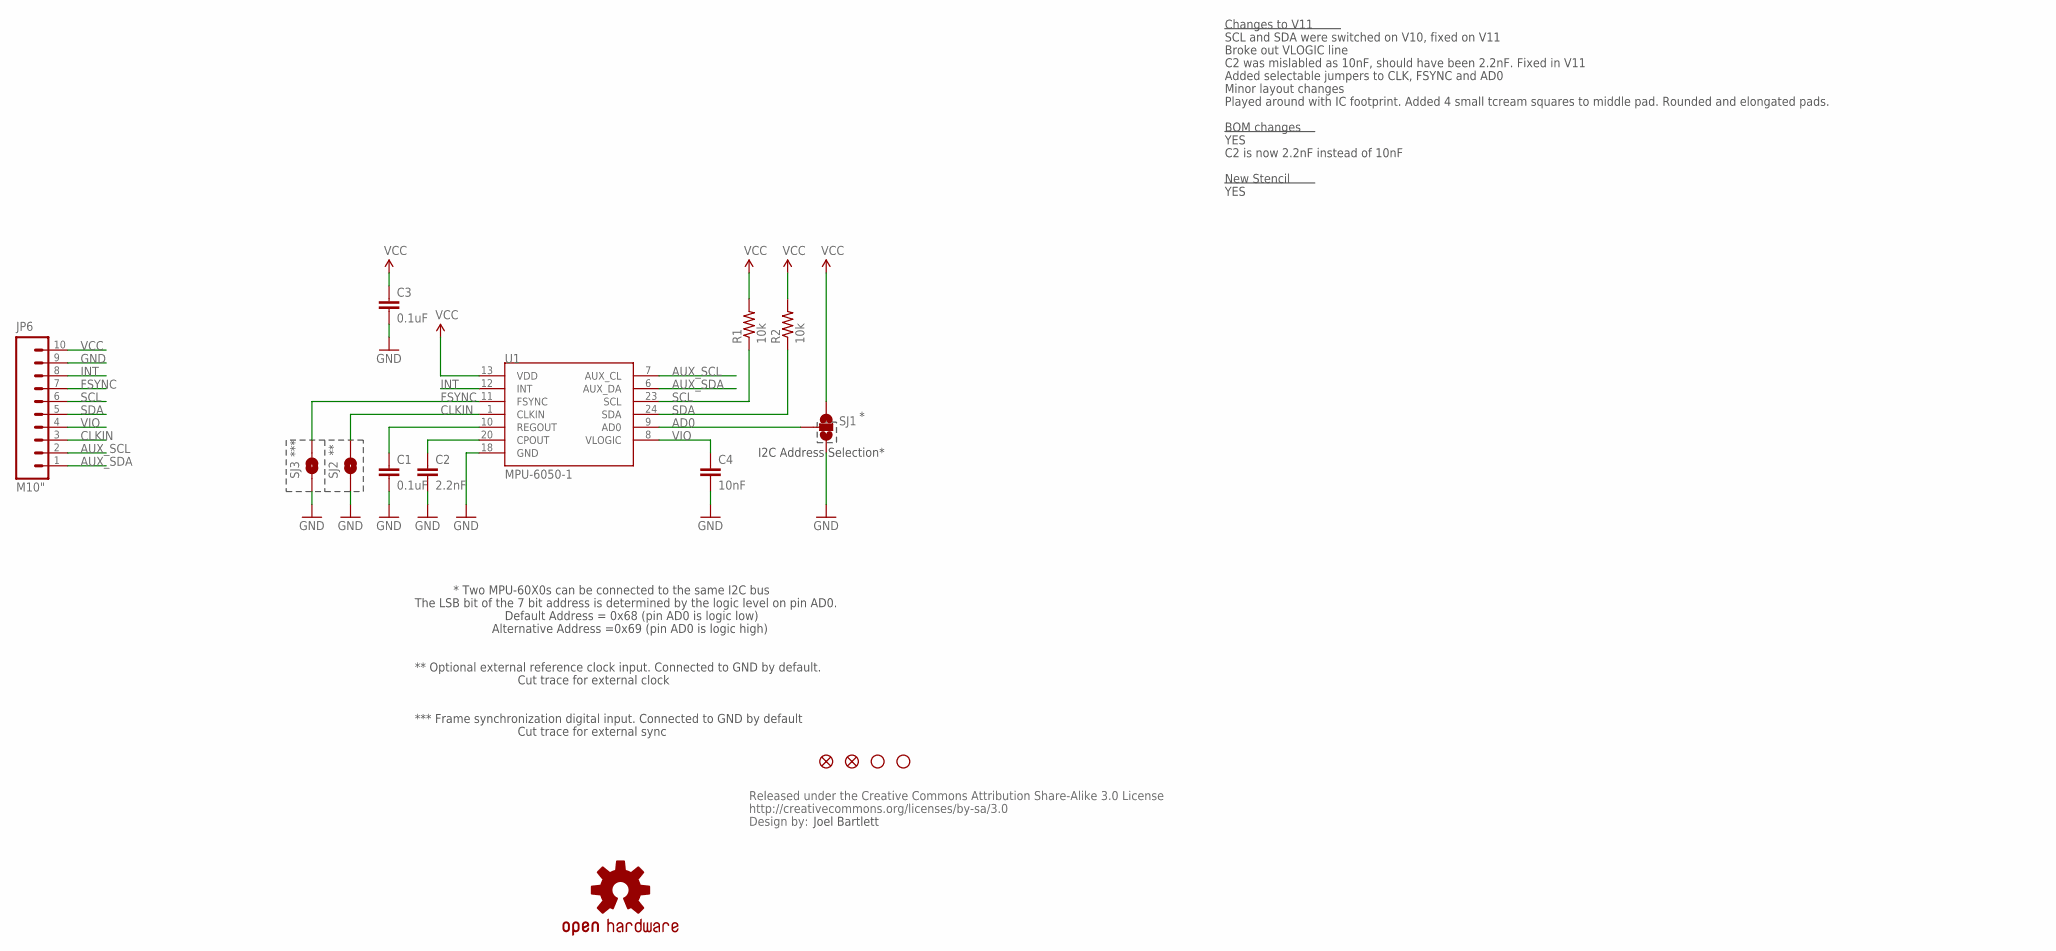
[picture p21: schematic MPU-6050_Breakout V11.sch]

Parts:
C1, C3: 0.1uF; 0402-CAP
C2: 2.2nF; 0402-CAP
C4: 10nF; 0402-CAP
JP2, JP5: FIDUCIALUFIDUCIAL; MICRO-FIDUCIAL
JP3, JP4: STAND-OFFTIGHT; STAND-OFF-TIGHT
JP6: M10"; 1X10
R1, R2: 10k; 0402-RES
SJ1: SOLDERJUMPER_2WAYPASTE2&3; SJ_3_PASTE2&3
SJ2, SJ3: SOLDERJUMPERTRACE; SJ_2S-TRACE
U1: MPU-6050-1; QFN-24-4MM2
U3: CREATIVE_COMMONS
U$1: OSHW-LOGOS; OSHW-LOGO-S

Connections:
AD0: SJ1.2, U1.9 (AD0)
AUX_SCL: JP6.2, U1.7 (AUX_CL)
AUX_SDA: JP6.1, U1.6 (AUX_DA)
CLKIN: JP6.3, SJ2.2, U1.1 (CLKIN)
FSYNC: JP6.7, SJ3.2, U1.11 (FSYNC)
GND: C1.2, C2.2, C3.2, C4.2, JP6.9, SJ1.3, SJ2.1, SJ3.1, U1.18 (GND)
INT: JP6.8, U1.12 (INT)
unnamed: C2.1, U1.20 (CPOUT)
unnamed: C1.1, U1.10 (REGOUT)
SCL: JP6.6, R1.1, U1.23 (SCL)
SDA: JP6.5, R2.1, U1.24 (SDA)
VCC: C3.1, JP6.10, R1.2, R2.2, SJ1.1, U1.13 (VDD)
VIO: C4.1, JP6.4, U1.8 (VLOGIC)

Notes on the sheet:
Joel Bartlett
I2C Address Selection*
*** Frame synchronization digital input. Connected to GND by default
***
Cut trace for external sync
* Two MPU-60X0s can be connected to the same I2C bus
Default Address = 0x68 (pin AD0 is logic low)
Alternative Address =0x69 (pin AD0 is logic high)
The LSB bit of the 7 bit address is determined by the logic level on pin AD0.
** Optional external reference clock input. Connected to GND by default.
Cut trace for external clock
Changes to V11
SCL and SDA were switched on V10, fixed on V11
C2 was mislabled as 10nF, should have been 2.2nF. Fixed in V11
Broke out VLOGIC line
BOM changes
New Stencil
YES
C2 is now 2.2nF instead of 10nF
Minor layout changes
Added selectable jumpers to CLK, FSYNC and AD0
Played around with IC footprint. Added 4 small tcream squares to middle pad. Rounded and elongated pads.

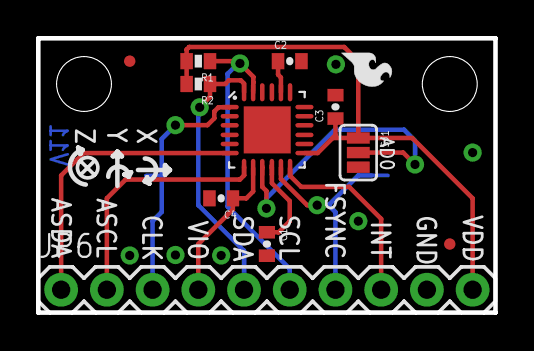
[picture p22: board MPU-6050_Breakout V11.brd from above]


Board: 2 copper layers, 25.4 x 15.2 mm, 20 parts (5 on the bottom side), 13 nets.

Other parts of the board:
U$2, U$3: SFE-LOGO-FLAME
U$4: SFE-NEW-WEB

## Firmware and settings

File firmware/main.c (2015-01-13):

/*
 QDC MK1 v1.0 - September 2014
 http://deralchemist.wordpress.com/
 Copyright (c) 2014 Matthias Kesenheimer.  All rights reserved.
 An Open Source Arduino based multicopter.
 
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
 You should have received a copy of the GNU General Public License
 along with this program. If not, see <http://www.gnu.org/licenses/>.
 */


/*
 * -----------> Wichtige Hinweise: <----------------
 *
 * Bevor der QDC zum ersten Mal geflasht wird, muss unbedingt FIRST_RUN
 * in def.c auf 1 gesetzt werden. Danach ein zweites mal mit FIRST_RUN = 0
 * flashen. Das ist nur nštig um zum ersten Mal das EEPROM zu formatieren,
 * danach wird dieser Aufruf kein weiteres Mal benštigt.
 *
 * PWM_init() aus/einkommentieren um die Motoren fŸr DEBUG-Zwecke aus/einzuschalten.
 *
 * In def.c muss der richtige Receiver ausgewŠhlt werden. Es stehen ein DSL oder 
 * ein DSM2 Receiver zur Auswahl.
 *
 */

#define F_CPU 32000000UL

#include <stdlib.h>
#include <avr/interrupt.h>
#include <util/delay.h>
#include <avr/io.h>
#include <math.h>
#include <string.h>
#include "avr_compiler.h"
#include "MPU6050.h"
#include "twi_master_driver.h"
#include "twi_master_driver.c"
#include "xeeprom.h"
#include "def.c"
#include "watchdog.c"
#include "time.c"
#include "IMU.c"
#include "config.c"
#include "output.c"
#include "receive.c"
#include "init.c"
#include "serial.c"
#include "filters.c"
#include "pid.c"
#include "led.c"

int main()
{
	setup();
	uint32_t sendTime = 0;
	uint32_t rcTime = 0;
	
	while (1) {
            
		//Zeitmessung
		currentTime = micros(); //Zeit in Einheiten von 10mus
		cycleTime = currentTime - previousTime; //1250mus ~1.2ms => 800Hz
		previousTime = currentTime;
		//Mittlere AusfŸhrungszeit
		sumTime += cycleTime;
		num++;
		if (num > 100) {
			meanTime = sumTime/100;
			num = 0;
			sumTime = 0;
		}
		
		//Integrationszeit
		dt = (float)cycleTime/1000000; //~0.001250s
		
		//Acc und Gyro Daten einlesen und integrieren
		Gyro_getADC();
		ACC_getADC();
            //first_order_comp_filter();
		second_order_comp_filter();
            //kalman_filter();
		pid();
            
		//alle 20ms rcData einlesen
		if (currentTime > rcTime) {
			USARTD0.CTRLB = USART_RXEN_bm;
			rcTime = currentTime + 20000;
			computeRC(); //berechnet die rcDaten -> rcData[channel] im Intervall [SIGNALMIN,SIGNALMAX]
            
                  //Wenn linker Stick nach rechts unten und
                  //rechter Stick nach links unten gedrŸckt wird kalibriert sich der QDC neu
                  if ( (rcThrottle < MINCHECK) && (rcAngle[ROLL] < -MAXCHECK) && (rcAngle[PITCH]< -MAXCHECK) && (rcYawRate < -MAXCHECK) ) {
                        SETLED1; SETLED2; SETLED3; SETLED4;
                        for (a=0; a<8; a++) {_delay_loop_2(65535);}	// ca. 1s
                        while (1) {}; //Watchdog ausloesen
                  }
                  
                  //Wenn linker Stick nach rechts unten und
                  //rechter Stick nach rechts unten gedrŸckt werden die Motoren gestartet/gestopt
                  if ( (rcThrottle < MINCHECK) && (rcAngle[ROLL] > MAXCHECK) && (rcAngle[PITCH]< -MAXCHECK) && (rcYawRate < -MAXCHECK) ) {
                        int first = 0;
                        
                        //Motoren ausschalten
                        if (motorsActive && !first) {
                              TCC0.CCA = 0;
                              TCC0.CCB = 0;
                              TCC0.CCC = 0;
                              TCC0.CCD = 0;
                              motorsActive = 0;
                              first = 1;
                        }
                        
                        //Motoren einschalten
                        if (!motorsActive && !first) {
                              motorsActive = 1;
                              first = 1;
                        }
                        
                        int i;
                        for (i=0; i<15; i++) {
                              SETLED1; SETLED2; SETLED3; SETLED4;
                              for (a=0; a<4; a++) {_delay_loop_2(65535);}	// ca. 500 ms
                              CLRLED1; CLRLED2; CLRLED3; CLRLED4;
                              for (a=0; a<4; a++) {_delay_loop_2(65535);}
                        }
                  }
		}
            
		//alle 20ms Daten an die GUI senden
		if (currentTime > sendTime) {
			sendTime = currentTime + 20000;
			switch (plot) {
				case NR:
                              //hier werden die Winkel mit 10 multipliziert,
                              //da die †bertragung nur mit Integerwerte funktionert.
                              //Es soll aber eine Auflšsung von 0.1 Grad erhalten bleiben,
                              //somit dividiert die GUI die erhaltenen Werte wieder durch 10.
					sendAnglesToGUI(compAngle[ROLL]*10, compAngle[PITCH]*10);
                              sendMotorsToGUI(motor[0]/1000, motor[1]/1000, motor[2]/1000, motor[3]/1000);
                              sendStatusToGUI(); //cycle Time usw.
					break;
				case PID:
					//sendPIDToGUI(pTerm[whichPIDToSend]/100, iTerm[whichPIDToSend]/100, dTerm[whichPIDToSend]/100);
                              sendMotorsToGUI(motor[0]/1000, motor[1]/1000, motor[2]/1000, motor[3]/1000);
                              sendStatusToGUI();
					break;
                        case DEB:
                              sendDebugToGUI(&debug[0],DEBUGITEMS);
                              sendStatusToGUI();
                              break;
				case NOT:
					sendStatusToGUI();
					break;
			}
		}
            
            ledThrottlePattern();
		mixTable();
            writeMotors();
		WDT_Reset();
	}
}

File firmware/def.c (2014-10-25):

/*
 QDC MK1 v1.0 - September 2014
 http://deralchemist.wordpress.com/
 Copyright (c) 2014 Matthias Kesenheimer.  All rights reserved.
 An Open Source Arduino based multicopter.
 
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
 You should have received a copy of the GNU General Public License
 along with this program. If not, see <http://www.gnu.org/licenses/>.
 */

//Alias
#define ROLL       0	//X
#define PITCH      1	//Y
#define YAW        2	//Z
#define THROTTLE   3	//Gas
#define AUX1       4
#define AUX2       5
#define AUX3       6
#define AUX4       7
#define PIDLEVEL   7    //hat bisher keine Funktion!
#define PIDITEMS   4

//Senden und Empfangen
#define PID		   0
#define NR		   1
#define NOT		   2
#define DEB        3
#define RECON	   1
#define RECOFF	   0

//entscheidet was an die GUI gesendet werden soll
static uint8_t plot = NOT; //am Anfang nichts senden : NOT
static uint8_t receiveOn = RECOFF;
static uint8_t iter = 0;
static uint8_t next = 1;
static uint8_t before = 0;
static uint8_t whichPIDToSend = 0;
static uint8_t motorsActive = 0;

//Konfigurationsvariablen
static struct
{
	uint8_t checkNewConf;
	uint8_t KP[PIDITEMS], KI[PIDITEMS], KD[PIDITEMS];
	int16_t angleTrim[2];
} conf;

static uint8_t EEMEM startAd[sizeof(conf)];
#define FIRST_RUN 0 //auf Eins setzen, wenn das Programm zum ersten Mal auf den QDC geladen wird. Ist nur dazu da, das EEPROM zu initialiseren/formatieren.

// WATCHDOG
#define WATCHDOG_TIMEOUT WDT_PER_2KCLK_gc

//Baudrate fŸr den DSM2 EmpfŠnger (rx31c-K1)
#define USART_BSCALED0 0
#define USART_BAUDRATED0 115200
#define BAUD_PRESCALED0 ((F_CPU / ((int16_t)(pow (2.0, USART_BSCALED0)) * (USART_BAUDRATED0 * 16UL)))  - 1)

//DEBUG UART //Daten an die GUI
#define USART_BSCALED1 0
#define USART_BAUDRATED1  19200 //19200// //38400 //115200 //57600
#define BAUD_PRESCALED1 ((F_CPU / ((int16_t)(pow (2.0, USART_BSCALED1)) * (USART_BAUDRATED1 * 16UL)))  - 1)

//DEBUG
#define DEBUGITEMS 10
static float debug[DEBUGITEMS];
static uint32_t meanTime = 0;
static uint32_t sumTime = 0;
static int num = 0;

//Zeitmanagment
//volatile uint32_t micro;
static uint32_t ms10 = 0;
static uint32_t currentTime = 0;
static uint32_t previousTime = 0;
static uint16_t cycleTime = 0;
static float dt = 0.00125; //sec
static uint8_t a = 0; //Laufvariable fŸr die _delay_loop2

//I2C Einstellungen fŸr MPU6050
#define BAUDRATE	400000
#define SLAVE_ADDRESS    0x69 //Adresse des MPU6050
#define TWI_BAUDSETTING TWI_BAUD(F_CPU, BAUDRATE)
TWI_Master_t twiMaster;
static uint8_t sendbuffer[2];
static uint8_t ra;	//temporaere Registeradresse zum Senden der I2C Daten

//Anzahl der Kalibrationsdurchgaenge Gyro/Acc
static uint16_t calibratingG = 10000;
static uint16_t calibratingA = 10000;
static float gyroOffset[3] = {0,0,0}; //alles int16_t
static float accOffset[3] = {0,0,0};
static float gyroADC[3] = {0,0,0};
static float accADC[3] = {0,0,0};
static float gyroRate[3] = {0,0,0};
static float gyroAngle[3] = {0,0,0};
static float accAngle[3] = {0,0,0};

//Empfaengersettings
#define RCMIN 1140 //Falls der EmpfŠnger andere Offset-Werte hat, hier Šndern
#define RCMAX 1860
#define RCANGLEMIN -500 //RC Winkel in 0.1 Grad Einheiten
#define RCANGLEMAX 500
#define RCTHROTTLEMIN 10
#define RCTHROTTLEMAX 1000
#define MOTORMIN 0 //PWM Minimalwert
#define MOTORMAX 60000 //PWM Maximalwert
#define MOTORMID (MOTORMAX + MOTORMIN)/2
#define MOTORRANGE (MOTORMAX - MOTORMIN)
#define MINCHECK 40
#define MAXCHECK 420
#define PIDRATIO 1 //Bestimmt den Einfluss der PID-Werte auf die Drehzahl der Motoren in Bezug auf den Gaswert von der Fernsteuerung
#define THROTTLERATIO 60
static uint32_t rcData[8]; // interval [1150,1850], aktuelle rcDaten gemittelt
static int32_t rcAngle[2]; // interval [-500,500]
static int32_t rcYawRate; // interval [-500,500]
static uint16_t rcThrottle; // interval [0,1000]

//PWM
#define MOTOR_CNT 4
#define PIDMIX(X,Y,Z) (THROTTLERATIO * rcThrottle + PIDRATIO * (axisPID[ROLL]*X + axisPID[PITCH]*Y + 1.414 * axisPID[YAW]*Z))
static uint32_t motor[MOTOR_CNT];

//PID-Settings
static float axisPID[PIDITEMS];
static float previousError[PIDITEMS] = {0,0,0,0};
static float error[PIDITEMS] = {0,0,0,0};
static float pTerm[PIDITEMS] = {0,0,0,0};
static float dTerm[PIDITEMS] = {0,0,0,0};
static float iTerm[PIDITEMS] = {0,0,0,0};
static float iSum[PIDITEMS] = {0,0,0,0};
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

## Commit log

2014-09-25 eagle Dateien bereinigt
    [Nanocopter_alt.brd, Nanocopter_alt.sch]
2014-09-27 Verbesserungen der GUI und unnuetzer Code entfernt
2014-09-28 Arbeit an der GUI
2014-09-28 Übermitteln von Statuswerten an die GUI hinzugefügt
2014-09-30 PID Werte eingestellt
2014-09-30 Test der PID Werte
2014-10-05 PWM Prescaler verringert
2014-10-05 Verbesserungen an der Hardware
    [Nanocopter_V2.brd, Nanocopter_V2.sch, mpu-9150_breakout.brd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]
2014-10-18 Arbeit an Schaltplan V2
    [Nanocopter.brd, Nanocopter_V2.brd, Nanocopter_V2.sch]
2015-03-31 Neuer Schaltplan V2.1. Die Schaltung wird jetzt in zwei Teile aufgeteilt: Flugcontroller (SimpleControl) und Motortreiber-platine (BaseFrame).
    [Nanocopter_V2.1.brd, Nanocopter_V2.1.sch, Nanocopter_V2.brd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]
2015-03-31 Dimensionen von SimpleControl aktualisiert
    [Nanocopter_V2.1.brd, Nanocopter_V2.1.sch]
2015-03-31 Arbeit an den Dimensionen
    [Nanocopter_V2.1.brd, Nanocopter_V2.1.sch]
2015-03-31 Abmessungen geändert
    [Nanocopter_V2.1.brd]

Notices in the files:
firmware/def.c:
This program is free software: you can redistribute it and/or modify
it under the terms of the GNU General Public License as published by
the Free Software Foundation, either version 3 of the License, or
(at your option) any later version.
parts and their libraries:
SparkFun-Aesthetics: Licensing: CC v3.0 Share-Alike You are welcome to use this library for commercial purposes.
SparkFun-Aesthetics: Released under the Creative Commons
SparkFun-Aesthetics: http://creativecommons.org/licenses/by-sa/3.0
